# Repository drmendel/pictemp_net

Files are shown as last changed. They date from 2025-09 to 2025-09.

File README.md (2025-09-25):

<div align="center">
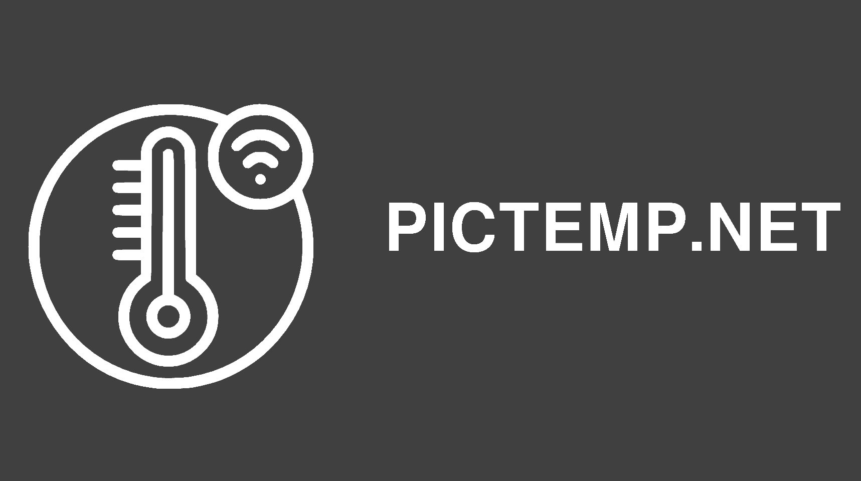
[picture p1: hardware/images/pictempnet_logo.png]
PICTEMP.NET Logo
  
</div>

## Overview

The **`PICTEMP.NET`** is a standalone IoT temperature sensor based on the *PIC18F97J60*, featuring TCP access over Ethernet using the *ENC28J60* ethernet controller. Includes custom firmware built on the Microchip TCP/IP stack and a compact KiCad-designed PC (similar to *PICDEM2.NET*) ideal for IoT, home automation, and industrial monitoring.

The project demonstrates a full-stack IoT solution:

- **Hardware**: A compact, efficient PCB designed in *KiCad*
- **Firmware**: Integrating sensor acquisition and network communication based on *Microchip Solutions v2011-06-02 TCP/IP Demo App*

The project was tested on the *PICDEM2.NET* development board, which ensured the firmware functionality before transitioning to the custom PCB.

## Hardware

### Core Components

- **Microcontroller:** PIC18F97J60  
- **Ethernet Controller:** ENC28J60 (external)  
- **Temperature Sensor:** TC1047x47  
- **Clock Sources:** 25 MHz, 32 kHz crystals  
- **Power Regulation:** LM2940S-5.0, TC1262-3.3  
- **LCD Display:** LCM-S01602DTR_M  
- **Connectivity:** RJ-12, RJ-45, barrel jack, pushbutton, testpoints

*The full list is available in [*pictempnet.csv*](hardware/pictempnet.csv).*

### Design priorities

- Compact footprint for embedded deployment  
- Efficient routing for signals and power  
- Smaller size to reduce cost and complexity    

### PCB Layout

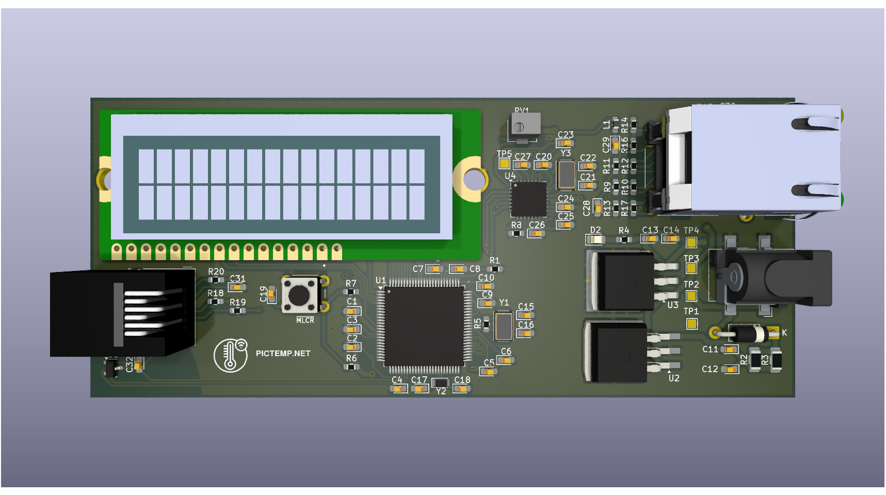
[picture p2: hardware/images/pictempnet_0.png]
PICTEMP.NET PCB Top Layer
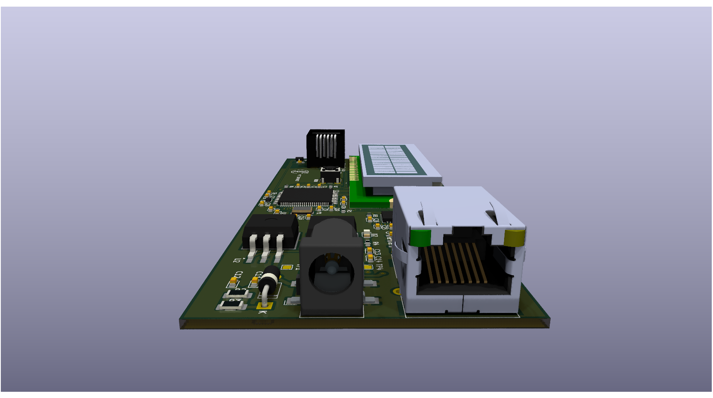
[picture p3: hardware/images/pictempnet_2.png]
PICTEMP.NET PCB Top Layer
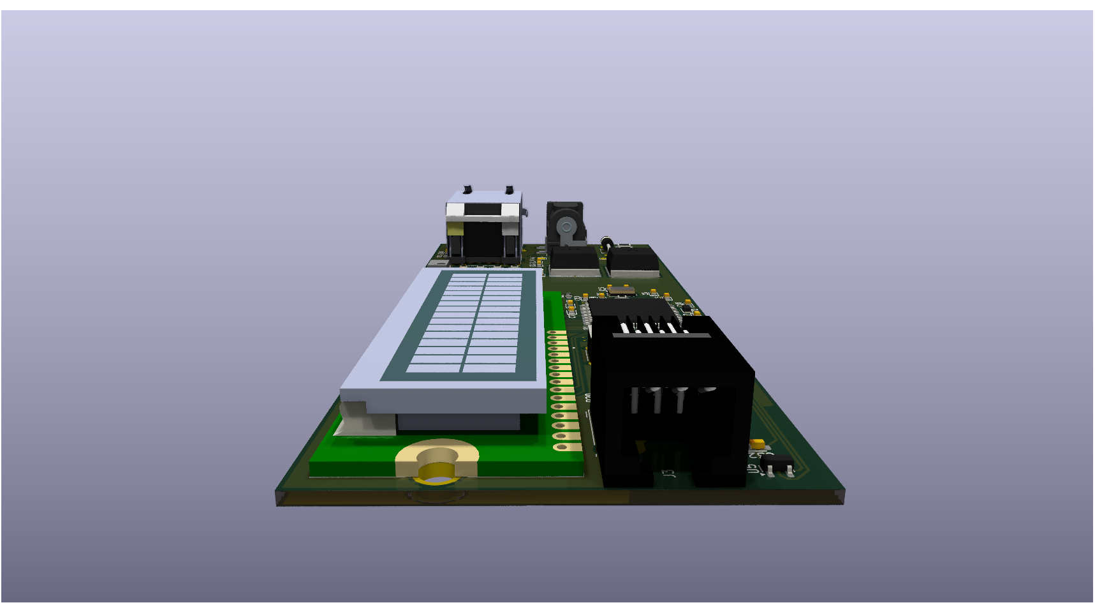
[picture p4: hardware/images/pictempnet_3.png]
PICTEMP.NET PCB Top Layer
|  |  |  |
|-|-|-|
| *Top view* | *Right view* | *Left view* |

*More images are available in the [images/](hardware/images) folder.*

## Firmware Architecture

The firmware is based on *Microchip Solutions v2011-06-02 TCP/IP Demo App*, modified to implement temperature sensing functionality. Key components include:  

- *`temperature_sensor.h` / `temperature_sensor.c`* – Interfaces directly with the temperature sensor IC, reading real-time measurements and providing functions to access the data.    
- *`GenericTCPIPServer.c`* – Derived from Microchip sources, enhanced for temperature sensor integration and real-time TCP access.

The firmware manages:  

- TCP connection handling and client requests  
- Temperature sensor sampling on TCP request
- Data buffering and formatting
- Efficient, low-latency response for real-time monitoring  

## Usage

### Project Configuration

The firmware is developed using *Microchip MPLAB X IDE*. It is strongly recommended to compile the project with this IDE due to complex configuration requirements.

In the project properties, set the following options:

- **Categories:** `C18-PICDN2_ENC28`  
- **Device:** `PIC18F97J60`  
- **Compiler Toolchain:** *[`C18 v3.47`](https://mplab-c18.software.informer.com/download/)*  

### Steps to Use

1. **Flash** the firmware to the custom *PCB* or the *PICDEM2.NET* development board.  
2. **Connect** the device to your network via Ethernet. The LCD will display the assigned IP address.  
3. **Access** temperature readings by sending the character `'t'` or `'T'` to *TCP port 2000*.

## Licensing

- **Hardware design**: Licensed under the [CERN-OHL-W-2.0](./hardware/LICENSE).  
- **Firmware**: Licensed under the terms of the [MICROCHIP SOFTWARE LICENSE AGREEMENT](./firmware/LICENSE).  

By **`DOWNLOADING`** or **`USING`** any part of this repository (including but not limited to source code, hardware design files, schematics, documentation, and images) through methods such as:
  - cloning the repository (`git clone ...`)  
  - downloading release archives (`.zip` / `.tar.gz`)  
  - forking the repository  
  - downloading individual files via the GitHub web interface  
  - retrieving the repository via GitHub API or GitHub CLI  
  - mirroring the repository

you **`AGREE`** to the applicable license terms, including the [MICROCHIP SOFTWARE LICENSE AGREEMENT](./firmware/LICENSE).

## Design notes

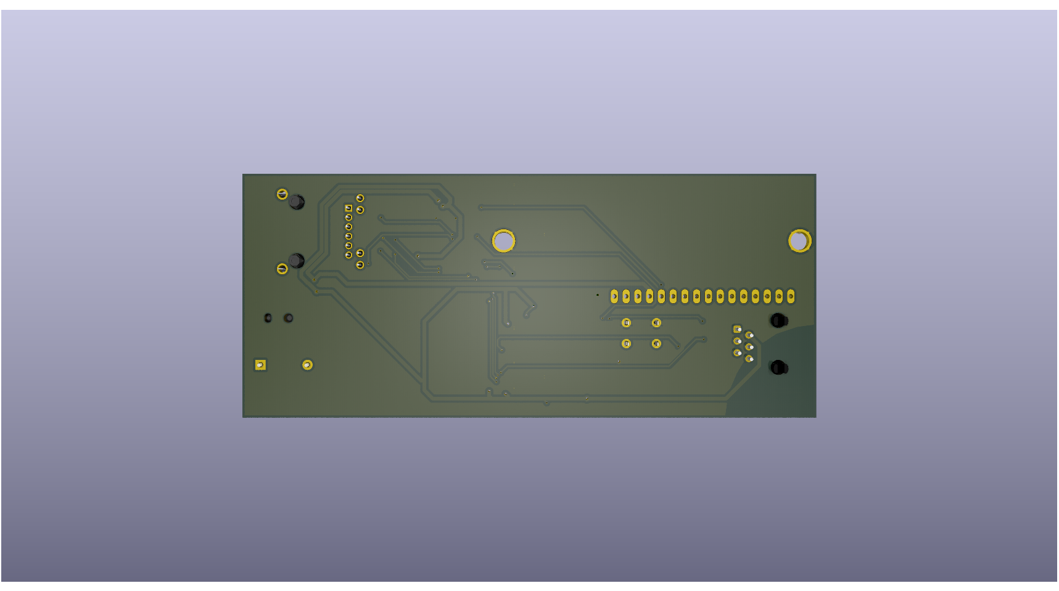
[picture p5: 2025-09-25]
hardware/images/pictempnet_1.png

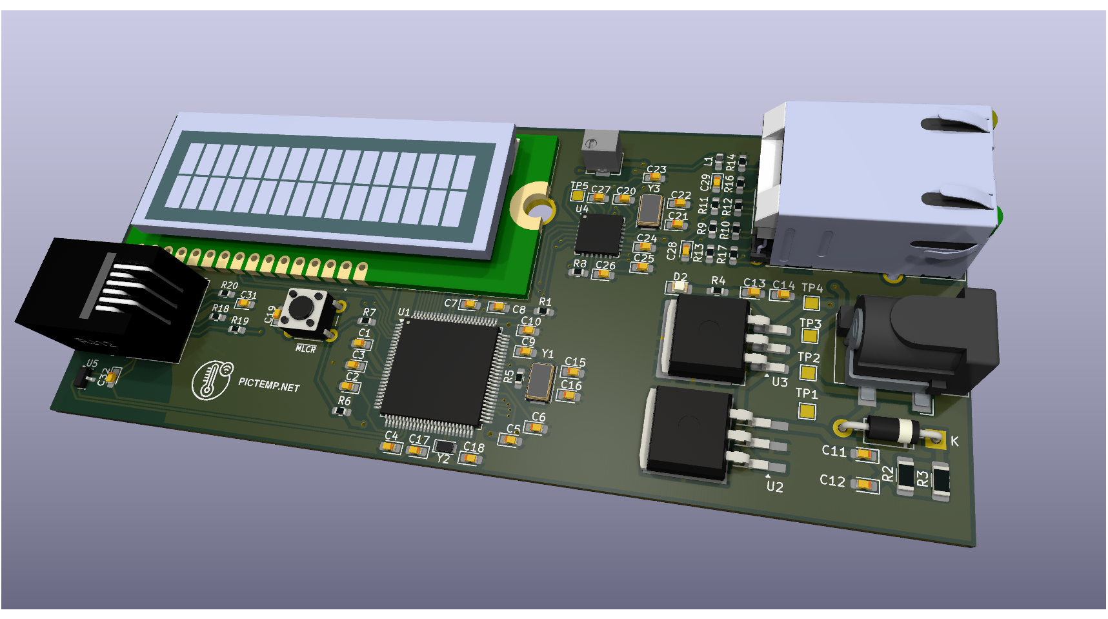
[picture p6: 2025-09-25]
hardware/images/pictempnet_4.png

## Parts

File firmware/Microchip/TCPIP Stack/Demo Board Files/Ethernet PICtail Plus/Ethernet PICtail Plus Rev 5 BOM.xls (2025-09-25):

02-01898 Rev 5 |  |  |  | PICtail Plus Ethernet
Count | ComponentName | RefDes | Value | Description | Vendor | Vendor # | Digikey # | RoHS
1 |  | U3 | ENC28J60 | Ethernet IC | Microchip |  |  | TRUE
7 | CAP0603 | C2, C3, C4, C6, C7, C13, C14 | .1uF | CAP SMT, 0.1uF 0603 CER 16V 10% X7R | NIC COMPONENTS CORP | NMC0603X7R104K16TRPF |  | TRUE
2 | CAP0603 | C5, C17 | 33pf | CAP CER 33PF 50V C0G 5% 0603 | TDK Corporation | C1608C0G1H330J | 445-1275-1-ND | TRUE
1 | CAP0805 | C12 | 10uF | CAP CER 10UF 6.3V Y5V 0805 | Murata | GRM21BF50J106ZE01L | 490-1746-1-ND | TRUE
1 | CRYSTAL_CS10 | Y1 | 25Mhz | CRYSTAL 25.0000 MHZ 18PF SMD | CITIZEN | CS10-25.000MABJTR | 300-8105-1-ND | TRUE
4 | RES0603 | R3, R4, R5, R6 | 49.9, 1% | RES 49.9 OHM 1/16W 1% 0603 SMD | Rohm | MCR03EZPFX49R9 | RHM49.9HCT-ND | TRUE
5 | RES0603 | R2, R7, R9, R11, R12 | 180 | RES 180 OHM 1/10W 5% 0603 SMD | Rohm | MCR03EZPJ181 | RHM180GCT-ND | TRUE
0 | RES0603 | R10 | No Load |  |  |  |  | N/A
1 | RES0603 | R8 | 2.32K, 1% | RES 2.32K OHM 1/10W 1% 0603 SMD | Rohm | MCR03EZPFX2321 | RHM2.32KHCT-ND | TRUE
1 | INDUCTOR-1210 | L1 | 60ohm | FERRITE 1.5A 60 OHM 1210 SMD | Steward | MI1210K600R-10 | 240-2416-1-ND | TRUE
1 |  | J1 |  | Mag Jack | Bel Stewart | 08B0-1X1T-36-F |  | TRUE
0 | Alternate | J1 |  | Pulse Jack | Pulse Engineering | JP011821UNL |  | TRUE

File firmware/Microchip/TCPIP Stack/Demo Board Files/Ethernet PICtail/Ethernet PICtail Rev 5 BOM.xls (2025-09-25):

02-01841 Rev 5 |  |  |  | Ethernet PICtail
Note: Use Vendor part number for reference, a few Digikey part numbers may be the lead version
Count | ComponentName | RefDes | Value | Description | Vendor | Vendor # | Digikey # | RoHS
1 | BRRECT-W02M | CR1 |  | RECTIFIER BRIDGE 1.5A 200V WOG | General Semiconductor | W02G-E4 | W02GGI-ND | TRUE
1 |  | U1 | 25C256 | EEPROM | Microchip | 25LC256-I/SN |  | TRUE
1 |  | U3 | ENC28J60 | Ethernet IC | Microchip | ENC28J60-I/ML |  | TRUE
1 | MC74VHCT125A-D | U2 |  | IC QUAD BUFF HS TRI-ST 14-SOIC | On Semiconductor | MC74VHCT125A-D | Newark 75C3053 | TRUE
1 | MC78XX_DPAC | Q2 |  | IC REGULATOR LDO 1A TO-263 | National Semiconductor | LM2940S-5.0/NOPB | LM2940S-5.0-ND | TRUE
0 | MC78XX_DPAC | Q1 | No Load | IC REGULATOR LDO TO-263 | National Semiconductor | LM3940IS-3.3 | LM3940IS-3.3-ND | N/A
1 | MC78XX_DPAC | Q1 |  | 500mA Fixed Output CMOS LDO | Microchip | TC1262-3.3VEB |  | TRUE
12 | CAP0603 | C1, C2, C3, C4, C6, C7, C8, C9, C11, C13, C14, C18 | .1uF | CAP SMT, 0.1uF 0603 CER 16V 10% X7R | NIC COMPONENTS CORP | NMC0603X7R104K16TRPF |  | TRUE
2 | CAP0603 | C5, C17 | 33pf | CAP CER 33PF 50V C0G 5% 0603 | TDK Corporation | C1608C0G1H330J | 445-1275-1-ND | TRUE
1 | CAP0805 | C12 | 10uF | CAP CER 10UF 6.3V Y5V 0805 | Murata | GRM21BF50J106ZE01L | 490-1746-1-ND | TRUE
2 | CAP B | C15, C16 | 33uF | CAP 33UF 10V ELECT VS SMD | Panasonic - ECG | EEE1AA330WR | PCE3175CT-ND | TRUE
1 | CAP_SMT_F | C10 | 220uF | CAP 220UF 25V ELECT VS SMD | Panasonic - ECG | EEE1EA221UP | PCE3187TR-ND | TRUE
1 | CRYSTAL_CS10 | Y1 | 25Mhz | CRYSTAL 25.0000 MHZ 18PF SMD | CITIZEN | CS10-25.000MABJTR | 300-8105-1-ND | TRUE
4 | RES0603 | R3, R4, R5, R6 | 49.9, 1% | RES 49.9 OHM 1/16W 1% 0603 SMD | Rohm | MCR03EZPFX49R9 | RHM49.9HCT-ND | TRUE
6 | RES0603 | R2, R7, R9, R10, R11, R12 | 180 | RES 180 OHM 1/10W 5% 0603 SMD | Rohm | MCR03EZPJ181 | RHM180GCT-ND | TRUE
1 | RES0603 | R8 | 2.7K, 1% | RES 2.70K OHM 1/10W 1% 0603 SMD | Rohm | MCR03EZPFX2701 | RHM2.70KHCT-ND | TRUE
1 | RES0603 | R1 | 100K | RES SMT, 100K-OHM 1/16W 5% 0603 | KOA | RK73B1JTTD104J |  | TRUE
1 | DJ005B | J11 |  | CONN, JACK, 2.5mm DC PC MOUNT | KYCON | KLD-0202-B |  | TRUE
1 | INDUCTOR-1210 | L1 | 60ohm | FERRITE 1.5A 60 OHM 1210 SMD | Steward | MI1210K600R-10 | 240-2416-1-ND | TRUE
1 | LED-0805 | D1 | GREEN | LED THIN 565NM GRN DIFF 0805 SMD | Lumex Opto | SML-LXT0805GW-TR | 67-1553-1-ND | TRUE
1 |  | J1 |  | Mag Jack | Bel Stewart | 08B0-1X1T-36-F |  | TRUE
0 | Alternate | J1 |  | Pulse Jack | Pulse Engineering | JP011821UNL |  | TRUE
1 |  | J2 |  | CONN HEADER .100 DUAL R/A 28POS | SAMTEC | TSW-114-08-G-D-RA |  | TRUE
1 |  | J3 |  | 2x14 header female | SAMTEC | SSW-114-01-T-D |  | TRUE
1 |  | None |  | 2x14 header female (ship loose in box) |  |  |  | TRUE
0 |  | J8, JP1, JP2, JP3 | No Load |  |  |  |  | N/A
0 |  | J4, J5, J6, J7 | No Load |  |  |  |  | N/A
1 |  | J9 |  | 1x3 header | SAMTEC | TSW-103-07-S-S |  | TRUE
1 | Load @ | J9 (pins 2&3) |  | 2 pin shorting jumper | AMP/TYCO | 382811-6 | A26227-ND | TRUE
0 |  | J10 | No Load | 2x6 header |  |  |  | N/A
1 |  | TP2 |  | TEST POINT, BLACK (0.063" HOLE) | COMPONENTS CORP | TP-106-01-00 |  | TRUE
2 |  | TP1, TP3 |  | TEST POINT, RED (0.063" HOLE) | COMPONENTS CORP | TP-106-01-02 |  | TRUE
Changes from Rev 3
C3 | Change from .01uF to .1uF
C12 | Change from electrolitic to ceramic
R12 | Add 200 ohm (new value)
R9 | Change from 100K to 200 ohm
R11 | Change from NL to 200 ohm
JP1, JP2, JP3 | Add No Load
C19 | Delete
Y1 | Change to new part
L1 | Change to RoHS part (-10 suffix)
C5, C17 | Change to 33pf
R9, R10, R11, R12 | Change to 180 Ohm

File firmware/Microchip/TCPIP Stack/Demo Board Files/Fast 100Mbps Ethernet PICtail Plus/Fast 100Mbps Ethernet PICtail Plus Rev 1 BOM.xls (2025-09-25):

02-02100 | Rev 1 |  | Microchip Fast 100Mbps Ethernet PICtailTM Plus
Count | RefDes | Value | Description | Vendor | Vendor Part Number | Mouser Part Number | Price 1 | Price 100 | Price 250 | Price 500 | Extension 100 | Extension 500 | RoHS | Comment
1 | U14 | NC7SZ57 | NOT NAND gate (SC70-6) | Fairchild Semiconductor | NC7SZ57P6X | 512-NC7SZ57P6X (http://www.mouser.com/Search/ProductDetail.aspx?qs=Q3c8oR7VdSob6m%252bML4LF0g%3d%3d) | $0.28 | $0.18 | $0.12 | $0.10 | $0.18 | $0.10 | TRUE
1 | U13 | NC7SZ04 | Inverter gate (SC70-5) | Fairchild Semiconductor | NC7SZ04P5X | 512-NC7SZ04P5X (http://www.mouser.com/Search/ProductDetail.aspx?qs=CR8BwU6haLeoOKbTbWr5WQ%3d%3d) | $0.19 | $0.12 | $0.08 | $0.07 | $0.12 | $0.07 | TRUE
1 | U3 | FST3125 | 4-bit Bus switch (TSSOP-14) | Fairchild Semiconductor | FST3125MTC | 512-FST3125MTC (http://www.mouser.com/Search/ProductDetail.aspx?qs=zGDcupr4zwNxWUl%252b5xBHsw%3d%3d) | $0.43 | $0.27 | $0.20 | $0.17 | $0.27 | $0.17 | TRUE
3 | U1, U2, U5 | FST3345 | 8-bit Bus switch (TSSOP-20) | Fairchild Semiconductor | FST3345MTC | 512-FST3345MTC (http://www.mouser.com/Search/ProductDetail.aspx?qs=MAkgEELEczQKCjIPKSg4pQ%3d%3d) | $0.52 | $0.22 | $0.19 | $0.17 | $0.66 | $0.52 | TRUE
1 | U8 | FST3257 | Quad 2:1 Multiplexer/Demultiplexer Bus Switch (TSSOP-16) | Fairchild Semiconductor | FST3257MTC | 512-FST3257MTC (http://www.mouser.com/Search/ProductDetail.aspx?qs=cbrHF9JAdyzaGwiPNvhfyw%3d%3d) | $0.52 | $0.30 | $0.22 | $0.19 | $0.30 | $0.19 | TRUE
1 | U4 | 74VHCT125 | Quad 3-state 5V TTL buffer (TSSOP-14) | On Semiconductor | MC74VHCT125ADTRG | 863-MC74VHCT125ADTRG (http://www.mouser.com/Search/ProductDetail.aspx?qs=%252b9%2fcbd0IE0Tn4bU7rbR7RQ%3d%3d) | $0.36 | $0.28 | $0.28 | $0.23 | $0.28 | $0.23 | TRUE
1 | D1 | MBR0540 | 500mA 50V Schottky Diode (SOD-123) | Fairchild Semiconductor | MBR0540 | 512-MBR0540 (http://www.mouser.com/Search/ProductDetail.aspx?qs=k%252b6EXM6KU1M%2f4zaj7pzWOw%3d%3d) | $0.11 | $0.08 | $0.07 | $0.05 | $0.08 | $0.05 | TRUE
1 | U6 | Si1307DL | 1.8V 0.91A P-Channel MOSFET (SC70-3) | Vishay Siliconix | SI1307DL-T1-E3 | 781-SI1307DL-E3 (http://www.mouser.com/Search/ProductDetail.aspx?qs=jcx%252b0HVgj2bRJdZ0ejbJbQ%3d%3d) | $0.28 | $0.23 | $0.23 | $0.22 | $0.23 | $0.22 | TRUE
1 | U7 | MCP1825 | 500mA 3.3V LDO with shutdown (SOT-223-5) | Microchip Technology | MCP1825T-3302E/DC | Microchip Direct: MCP1825T-3302E/DC (http://www.microchipdirect.com/productsearch.aspx?Keywords=MCP1825T-3302E%2fDC) | $0.00 | $0.00 | $0.00 | $0.00 | $0.00 | $0.00 | TRUE
1 | U9 | ENC624J600 | ENC624J600 10/100 Ethernet controller (TQFP-64 10x10x1) | Microchip Technology | ENC624J600-I/PT | 579-ENC624J600-I/PT (http://www.mouser.com/Search/ProductDetail.aspx?qs=sGAEpiMZZMvbYnN5EaJWBIREahSXEh7PrvOskHFN3mo%3d) | $0.00 | $0.00 | $0.00 | $0.00 | $0.00 | $0.00 | TRUE
1 | Y1 | 25MHz | Fundamental 25MHz +/-20PPM 18pF 500uW -20C to +70C crystal | ABRACON | ABMM-25.000MHZ-B2-T | 815-ABMM-25-B2-T (http://www.mouser.com/Search/ProductDetail.aspx?qs=aMAwYrhw3fjtGmDmGUYkhw%3d%3d) | $0.88 | $0.53 | $0.50 | $0.49 | $0.53 | $0.49 | TRUE
1 | J7 |  | Ethernet RJ-45 Jack with integrated magnetics and LEDs (-40C to +85C) | Bel Stewart | 08B0-1X1T-36-F | Arcadian Sales: 08B0-1X1T-36-F (http://arcadiansales.com/belbel-fusestewart-connector/rj45-connector-with-ethernet-andor-poe---poeplus/08B01X1T36F/) | $4.60 | $3.16 | $3.16 | $2.73 | $3.16 | $2.73 | TRUE
1 | R5 | 1M | 1M ohm 5% 0603 resistor | KOA Speer | RK73B1JTTD105J | 660-RK73B1JTTD105J (http://www.mouser.com/Search/ProductDetail.aspx?qs=MOfRNGxtlbKRrhpyH1P1mA%3d%3d) | $0.06 | $0.02 | $0.02 | $0.02 | $0.02 | $0.02 | TRUE
18 | R7, R13, R14, R23, R24, R25, R26, R27, R28, R29, R30, R34, R36, R37, R39, R43, R42, R45 | 100k | 100K ohm 5% 0603 resistor | KOA Speer | RK73B1JTTD104J | 660-RK73B1JTTD104J (http://www.mouser.com/Search/ProductDetail.aspx?qs=oWZKZnQ95OoPzlg%252bHmLYKg%3d%3d) | $0.06 | $0.02 | $0.004 | $0.004 | $0.29 | $0.07 | TRUE
1 | R22 | 12.4K | 12.4K ohm 1% 0603 resistor | Vishay/Dale | CRCW060312K4FKEA | 71-CRCW0603-12.4K-E3 (http://www.mouser.com/Search/ProductDetail.aspx?qs=8tsW7z%2fc78of4VB3wUPkkg%3d%3d) | $0.06 | $0.02 | $0.02 | $0.02 | $0.02 | $0.02 | TRUE
3 | R35, R40, R41 | 10k | 10K ohm 5% 0603 resistor | KOA Speer | RK73B1JTTD103J | 660-RK73B1JTTD103J (http://www.mouser.com/Search/ProductDetail.aspx?qs=hmtrJ2UjXcBKRTcwO9LloQ%3d%3d) | $0.06 | $0.02 | $0.02 | $0.02 | $0.06 | $0.05 | TRUE
1 | R4 | 1k | 1K ohm 5% 0603 resistor | KOA Speer | RK73B1JTTD102J | 660-RK73B1JTTD102J (http://www.mouser.com/Search/ProductDetail.aspx?qs=ySlnPdhAnF0vPhOsRGbH%252bQ%3d%3d) | $0.06 | $0.02 | $0.02 | $0.02 | $0.02 | $0.02 | TRUE
2 | R19, R20 | 180 | 180 ohm 5% 0603 resistor | KOA Speer | RK73B1JTTDD181J | 660-RK73B1JTTDD181J (http://www.mouser.com/Search/ProductDetail.aspx?qs=eQc%252bYniTHCeW0PXkL8Pyjg%3d%3d) | $0.05 | $0.01 | $0.01 | $0.003 | $0.01 | $0.01 | TRUE
4 | R1, R2, R3, R32 | 100 | 100 ohm 5% 0603 resistor | KOA Speer | RK73B1JTTD101J | 660-RK73B1JTTD101J (http://www.mouser.com/Search/ProductDetail.aspx?qs=WYsh1TcxAFWszMVYT3llKQ%3d%3d) | $0.06 | $0.02 | $0.02 | $0.02 | $0.08 | $0.06 | TRUE
4 | R8, R9, R17, R18 | 49.9 | 49.9 ohm 1% 0603 resistor | Vishay/Dale | CRCW060349R9FKEB | 71-CRCW060349R9FKEB (http://www.mouser.com/Search/ProductDetail.aspx?qs=C0xaqriB68iwcu6QmKL3vw%3d%3d) | $0.06 | $0.02 | $0.01 | $0.01 | $0.08 | $0.06 | TRUE
1 | R6 | 10 | 10 ohm 1% 1/12W 0603 resistor | Vishay/Dale | CRCW060310R0FKEB | 71-CRCW060310R0FKEB (http://www.mouser.com/Search/ProductDetail.aspx?qs=KP%252bPudsHLdwtRLMc%252bPMrxQ%3d%3d) | $0.06 | $0.02 | $0.02 | $0.02 | $0.02 | $0.02 | TRUE
1 | R15 | 0 | 0 ohm 5% 0603 resistor | Vishay/Dale | CRCW06030000Z0EA | 71-CRCW0603-0-E3 (http://www.mouser.com/Search/ProductDetail.aspx?qs=uFJqmf%2f3rbbVtxvMdbYUaQ%3d%3d) | $0.06 | $0.02 | $0.02 | $0.02 | $0.02 | $0.02 | TRUE
0 | R10, R11, R12, R16, R38 | No Load
1 | C11 | 10uF | 10uF +80%/-20% 4V 0805 ceramic capacitor | Murata | GRM219R60J106KE19D | 81-GRM219R60J106KE9D (http://www.mouser.com/Search/ProductDetail.aspx?qs=Ilq%252bLDnc%2fNgDxdJFi6Qw%252bA%3d%3d) | $0.09 | $0.08 | $0.08 | $0.07 | $0.08 | $0.07 | TRUE
1 | C6 | 4.7uF | 4.7uF +80%/-20% 6.3V 0603 ceramic capacitor | Murata | GRM188F50J475ZE20D | 81-GRM188F50J475ZE20 (http://www.mouser.com/Search/ProductDetail.aspx?qs=koHpCXkX%252bXWPno0u3vcZ7w%3d%3d) | $0.19 | $0.07 | $0.07 | $0.04 | $0.07 | $0.04 | TRUE
1 | C7 | 1uF | 1uF +80%/-20% 6.3V 0603 ceramic capacitor | Murata | GRM188R60J105KA01D | 81-GRM39R105K6.3 (http://www.mouser.com/Search/ProductDetail.aspx?qs=dddcrN876Gomyq%2fPjh7oaA%3d%3d) | $0.14 | $0.04 | $0.04 | $0.02 | $0.04 | $0.02 | TRUE
10 | C4, C8, C12, C17, C21, C23, C28, C31, C34, C37, | 0.1uF | 0.1uF +80%/-20% 16V 0603 ceramic capacitor | Kemet | C0603C104Z3VACTU | 80-C0603C104Z3V (http://www.mouser.com/Search/ProductDetail.aspx?qs=t9q%2f2xDdjt8I7iMfh2CPDg%3d%3d) | $0.05 | $0.01 | $0.01 | $0.01 | $0.06 | $0.05 | TRUE
10 | C9, C13, C15, C18, C22, C24, C29, C32, C35, C38 | 0.01uF | 0.01uF +80%/-20% 16V 0603 ceramic capacitor | Kemet | C0603C103J5RAC7411 | 80-C0603C103J5R7411 (http://www.mouser.com/Search/ProductDetail.aspx?qs=r%2fVmNO8Tjq5w03%252blhuR%2fbA%3d%3d) | $0.05 | $0.01 | $0.01 | $0.01 | $0.08 | $0.08 | TRUE
2 | C16, C20 | 6.8nF | 6.8nF +/-10% 16V 0603 ceramic capacitor | Kemet | C0603C682K5RACTU | 80-C0603C682K5R (http://www.mouser.com/Search/ProductDetail.aspx?qs=E5l%252bIPT91Puurjber%2feoHQ%3d%3d) | $0.05 | $0.02 | $0.01 | $0.01 | $0.04 | $0.01 | TRUE
2 | C26, C27 | 27pF | 27pF +/-5% 16V 0603 NP0/C0G ceramic capacitor | Kemet | C0603C270J5GACTU | 80-C0603C270J5G (http://www.mouser.com/Search/ProductDetail.aspx?qs=tmo4rc6ZD9Wc1Km2xObD4A%3d%3d) | $0.05 | $0.02 | $0.01 | $0.01 | $0.04 | $0.02 | TRUE
0 | C10, C19, C30, C33, C36, C39, C44 | No Load
3 | JP9, JP10, JP11 | 1x3 header | 1x3 pin thru-hole male header 0.1 inch pitch | Molex | 22-28-4032 | 538-22-28-4032 (http://www.mouser.com/Search/ProductDetail.aspx?qs=d9fIA1aNikShPBuXG7gmfA%3d%3d) | $0.11 | $0.09 | $0.08 | $0.06 | $0.27 | $0.18 | TRUE
4 | JP2, JP3, JP7, JP8 | 1x2 header | 1x2 pin thru-hole male header 0.1 inch pitch | Molex | 22-28-5020 | 538-22-28-5020 (http://www.mouser.com/Search/ProductDetail.aspx?qs=l%252bWx29wYPrzoqPHV3Welgw%3d%3d) | $0.08 | $0.07 | $0.06 | $0.05 | $0.26 | $0.20 | TRUE
1 | J4 | 2x14 header | 2x14 pin thru-hole male right angle header 0.1 inch pitch | Samtec | TSW-114-08-T-D-RA | Digikey: SAM1049-14-ND (http://search.digikey.com/scripts/DkSearch/dksus.dll?Detail&name=SAM1049-14-ND) | $2.45 | $1.81 | $1.81 | $1.43 | $1.81 | $1.43 | TRUE
1 | J3 | 2x3 header | 2x3 pin thru-hole male right angle header 0.1 inch pitch | Samtec | TSW-103-08-T-D-RA | Digikey: SAM1049-03-ND (http://search.digikey.com/scripts/DkSearch/dksus.dll?Detail&name=SAM1049-03-ND) | $1.68 | $1.24 | $1.24 | $0.98 | $1.24 | $0.98 | TRUE
0 | J6, J8, J9, J10 | No Load
6 | JP2, JP7, JP8, JP9, JP10, JP11 | Load@ JP2, (JP7, JP8 hang on one pin), (JP10 top two pins), (JP9, JP11 bottom two pins) | 1x2 pin jumper shunt 0.1 inch pitch | Sullins Connector Solutions | SPC02SYAN | Digikey: S9001-ND (http://search.digikey.com/scripts/DkSearch/dksus.dll?Detail&name=S9001-ND) | $0.09 | $0.07 | $0.05 | $0.05 | $0.44 | $0.29 | TRUE
0 | J5 | No Load
2 | TP3, TP4 |  | Test point, black (0.052" hole) | Kobiconn | 151-103-RC | 151-103-RC (http://www.mouser.com/Search/ProductDetail.aspx?qs=RH7ho1lbOmmmFptH%252bQFkig%3d%3d) | $0.30 | $0.20 | $0.15 | $0.13 | $0.40 | $0.26 | TRUE
1 | TP2 |  | Test point, red (0.052" hole) | Kobiconn | 151-107-RC | 151-107-RC (http://www.mouser.com/Search/ProductDetail.aspx?qs=iv5aS%252bKJODNJ8P%252bmN89Zyw%3d%3d) | $0.30 | $0.20 | $0.20 | $0.15 | $0.20 | $0.15 | TRUE
1 | - | 5' Cable | 5' Cat5e (or better) Ethernet patch cable | Cable and Connector Technologies | 5' Category 5e Patch Cable - Black | CCT: 5' Category 5e Patch Cable - Black (http://www.callcct.com/Shop/5-Category-5e-Patch-Cable) | $1.42 | $1.39 | $1.35 | $1.35 | $1.39 | $1.35
1 | - |  | PCB | Advanced Circuits |  |  | $5.00 | $5.00 | $5.00 | $5.00 | $5.00 | $5.00
 |  |  |  |  |  |  | Total |  |  |  | $17.83 | $15.25

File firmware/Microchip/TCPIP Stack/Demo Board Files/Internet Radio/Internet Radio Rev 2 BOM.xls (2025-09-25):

02-02027 | Rev 2 |  |  | Internet Radio
Count | ComponentName | RefDes | Value | Description | Vendor | Vendor # | Digikey # | RoHS
1 | DIODE | D4 |  | SMD Transient Voltage Suppression Arrays | AVX | MG054S05X150DP |  | TRUE
1 | DIODE_SOD-323 | D5 |  | DIODE SCHOTTKY 0.5A 20V SOD-123 | Fairchild Semiconductor | MBR0520L | MBR0520LCT-ND | TRUE
1 | MGSF1N02LT1_SOT23 | Q1 |  | MOSFET N-CHAN 750MA 20V SOT23 | ON Semiconductor | MGSF1N02LT1G | MGSF1N02LT1GOSCT-ND | TRUE
1 | PIC18F67J60 | U1 |  |  | Microchip | PIC18F67J60-I/PT |  | TRUE
1 | TC55-SOT89 | U5 |  | Voltage Regulator | Microchip | MCP1703T-3302E/MB |  | TRUE
2 | 23K256_SOIC150 | U4, U6 |  | 32K x 8 serial SRAM | Microchip | 23K256-I/SN |  | TRUE
1 | VS1011_LQFP48 | U2 |  | MP3 Decoder IC | VLSI | VS1011E-L |  | TRUE
1 | OLED_HS1101A | LCD1 |  |  |  |  |  | TRUE
1 | LED-0805 | D3 |  | LED THIN 565NM GRN DIFF 0805 SMD | Lumex Opto/Components | SML-LXT0805GW-TR | 67-1553-1-ND | TRUE
2 | CAP0603 | C27, C28 | 22pf | CAP CER 22PF 50V C0G 5% 0603 | TDK Corporation | C1608C0G1H220J | 445-1273-1-ND | TRUE
2 | CAP0603 | C7, C8 | 33pf | CAP CER 33PF 50V C0G 5% 0603 | TDK Corporation | C1608C0G1H330J | 445-1275-1-ND | TRUE
1 | CAP0603 | C30 | 1nF | CAP 1000PF 100V CERAMIC X7R 0603 | Panasonic - ECG | ECJ-1VB2A102K | PCC1952TR-ND | TRUE
2 | CAP0603 | C35, C36 | 10nF | CAP 10000PF 25V CERM X7R 0603 | Panasonic - ECG | ECJ-1VB1E103K | PCC1763TR-ND | TRUE
2 | CAP0603 | C26, C37 | 47nF | CAP 47000PF 50V CERM Y5V 0603 | Panasonic - ECG | ECJ-1VF1H473Z | PCC1805TR-ND | TRUE
17 | CAP0603 | C1, C2, C3, C4, C5, C6, C10, C11, C14, C15, C18, C23, C25, C29, C32, C38,C39 | .1uF | CAP .1UF 16V CERAMIC Y5V 0603 | Panasonic - ECG | ECJ-1VF1C104Z | PCC1788TR-ND | TRUE
3 | CAP0603 | C9, C16, C19 | 1uF | CAP SMT, 1.0uF 0603 CER 16V 10% X5R | PANASONIC | ECJ-1VB1C105K | PCC2224CT-ND | TRUE
1 | CAP0603 | C13 | 4.7uF | CAP CERAMIC 4.7UF 6.3V X5R 0603 | Panasonic - ECG | ECJ-1VB0J475M | PCC2318CT-ND | TRUE
1 | CAP0805 | C31 | 2.2uF | CAP 2.2UF 25V CERAMIC F 0805 | Panasonic - ECG | ECJ-2FF1E225Z | PCC2231CT-ND | TRUE
1 | CAP0805 | C20 | 10uF | CAP CER 10UF 6.3V Y5V 0805 | Murata | GRM21BF50J106ZE01L | 490-1746-1-ND | TRUE
1 | CAP3528 | C34 | 6.8uF | CAP TANTALUM 6.8UF 16V 20% SMD | Kemet | B45196H3685M209 | 495-2235-1-ND | TRUE
1 | CAP_POL_3528 | C17 | 10uF | CAPACITOR TANT 10UF 16V 10% SMD | Kemet | T491B106K016AT | 399-3706-1-ND | TRUE
1 | CAP_SMT_F | C33 | 220uF | CAP 220UF 25V ELECT VS SMD | Panasonic - ECG | ECE-V1EA221UP | PCE3187CT-ND | TRUE
1 | CC_1008LS | L3 | 10uH | 1008PS Series Power Chip Inductors | COILCRAFT | 1008PS-103KLB |  | TRUE
1 | DO1606 | L2 | 10uH | 1606 Series Power Chip Inductors | COILCRAFT | DO1606T-103MBL |  | TRUE
1 | INDUCTOR-1210 | L1 | 60ohm | FERRITE 1.5A 60 OHM 1210 SMD | Steward | MI1210K600R-10 | 240-2416-1-ND | TRUE
1 | CRYSTAL_CS10 | Y1 | 25Mhz | CRYSTAL 25.0000 MHZ 18PF SMD | CITIZEN | CS10-25.000MABJTR | 300-8105-1-ND | TRUE
1 | CRYSTAL_CS10 | Y2 | 24.576Mhz | CRYSTAL 24.5760 MHZ 18PF SMD | CITIZEN | CS10-24.576MABJ-UT | 300-8104-1-ND | TRUE
1 |  | J1 |  | Mag Jack | Bel Stewart | 08B0-1X1T-36-F |  | TRUE
1 | DJ005B | J3 |  | CONN JACK POWER 2.1MM PCB | CUI Inc | PJ-102A | CP-102A-ND | TRUE
1 | PHONE_SJ3505 | J2 |  | CONN 3.5MM RTANG STEREO JACK PCB | CUI Inc | SJ-3505 | CP-3505-ND | TRUE
1 | RJ11_6PIN | J4 |  | CONN, MOD JACK 6-6 SIDE ENTRY LOW PROFILE | AMP/TYCO | 555165-1 | A9031-ND | TRUE
3 | RES0603 | R29, R30, R31 | 10 Ohm | RES 10 OHM 1/10W 5% 0603 SMD | Panasonic - ECG | ERJ-3GEYJ100V | P10GTR-ND | TRUE
2 | RES0603 | R20, R21 | 20 Ohm | RES 20 OHM 1/10W 5% 0603 SMD | Panasonic - ECG | ERJ-3GEYJ200V | P20GTR-ND | TRUE
4 | RES0603 | R4, R5, R7,R8 | 49.9, 1% | RES 49.9 OHM 1/16W 1% 0603 SMD | Rohm | MCR03EZPFX49R9 | RHM49.9HCT-ND | TRUE
3 | RES0603 | R6, R9, R12 | 180 | RES 180 OHM 1/10W 5% 0603 SMD | Rohm | MCR03EZPJ181 | RHM180GCT-ND | TRUE
1 | RES0603 | R2 | 2.26K, 1% | RES 2.26K OHM 1/10W 1% 0603 SMD | Panasonic - ECG | ERJ-3EKF2261V | P2.26KHCT-ND | TRUE
6 | RES0603 | R10, R11, R14, R17, R18, R23 | 10K | RES SMT, 10K-OHM 1/10W 5% 0603 | Panasonic - ECG | ERJ-3GEYJ103V | P10KGTR-ND | TRUE
4 | RES0603 | R22, R32, R33, R34 | 100K | RES 100K OHM 1/10W 5% 0603 SMD | Panasonic - ECG | ERJ-3GEYJ104V | P100KGTR-ND | TRUE
1 | RES0603 | R16 | 110K 1% | RES 110K OHM 1/10W 1% 0603 SMD | Panasonic - ECG | ERJ-3EKF1103V | P110KHTR-ND | TRUE
1 | RES0603 | R13 | 820K | RES 820K OHM 1/10W 5% 0603 SMD | Panasonic - ECG | ERJ-3GEYJ824V | P820KGTR-ND | TRUE
1 | RES0603 | R15 | 931K 1% | RES 931K OHM 1/10W 1% 0603 SMD | Panasonic - ECG | ERJ-3EKF9313V | P931KHTR-ND | TRUE
1 | RES0603 | R19 | 1M | RES SMT, 1.0M-OHM 1/10W 5% 0603 | YAGEO/PHYCOMP | RC0603JR-071ML |  | TRUE
1 | RES0805 | R24 | 0.12 ohm | RES .12 OHM 1/2W 1% 1206 SMD | Susumu Co Ltd | RL1632R-R120-F | RL16R.12FCT-ND | TRUE
2 | RES1206 | R25, R26 | 2 Ohm | RES 2.00 OHM 1/4W 1% 1206 SMD | Rohm | MCR18EZHFL2R00 | RHM2.00FCT-ND | TRUE
3 | SW-PUSH_SMT | S1, S2, S3 |  | SWITCH LT TOUCH 6X3.5 100GF SMD | Panasonic - ECG | EVQ-PJS04K | P8048SCT-ND | TRUE
4 |  |  |  | BUMPON TALL TAPER SQ .50X.23 BK | 3M/ESM | SJ-5518 (BLACK) | SJ5518-0-ND | TRUE
0 | SIP_4 |  | No Load
1 | PCB |  |  |  | Advanced Circuits | 05-60142_REV_C |  | TRUE

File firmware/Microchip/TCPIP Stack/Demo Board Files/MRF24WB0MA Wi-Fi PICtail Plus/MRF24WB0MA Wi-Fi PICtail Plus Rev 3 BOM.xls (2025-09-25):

02-02122 | Rev 3 |  |  | MRF24WB0MA Wi-Fi PICtail Plus Daughter Board
Count | ComponentName | RefDes | Value | Discription | Vendor | Vendor # | Digikey # | Mouser # | Price | Extension | RoHS | Comments
1 | G2100_Module | U1 |  | 2.4GHz 802.11b Ultra Low Power Transceiver | Microchip | MRF24WB0MA |  |  | $0.000 | $0.000 | TRUE
1 | MCP1700_SOT89 | U2 |  | CMOS low dropout positive voltage regulator | Microchip | MCP1700T-3302E/MB |  |  | $0.000 | $0.000 | TRUE
3 | CAP0402 | C1, C2, C3 | 1uF | CAP 1UF 6.3V CERAMIC X5R 10% 0603 | Murata | GRM188R60J105KA01D |  | 81-GRM39R105K6.3 | $0.036 | $0.108 | TRUE
1 | CAP1206 | C4 | 100uF | Tantalum Cap 100uF 6.3volts 10% "C" case | Vishay/Sprague | 293D107X96R3C2TE3 | 718-1058-2-ND |  | $0.226 | $0.226 | TRUE
5 | RES0603 | R1, R2. R3. R4. R9 | 10K | RES 4.7K OHM 1/10W 5% 0603 SMD | Panasonic - ECG | ERJ-3GEYJ472V | P4.7KGTR-ND |  | $0.004 | $0.022 | TRUE
1 | RES0603 | R6 | 10K | RES 10K OHM 1/10W 5% 0603 SMD | Panasonic - ECG | ERJ-3GEYJ103V | P10KGTR-ND |  | $0.004 | $0.004 | TRUE
1 | RES0603 | R7 | 1M | RES 1.0M OHM 1/10W 5% 0603 SMD | Panasonic - ECG | ERJ-3GEYJ105V | P1.0MGTR-ND |  | $0.004 | $0.004 | TRUE
0 | RES0603 | R5 | No Load
0 | HDR2X4 | J4 | No Load
0 | TP-125R63 | TP1, TP2 | No Load
1 | HDR2X14 | J1 | (28 pins) | CONN HEADER .100 DUAL R/A 72POS | Sullins Electronics Corp. | PZC36DBDN | S2141-36-ND |  | $2.810 | $2.81 | TRUE | Cut to 2x14 pins
1 | PCB |  |  |  | Advanced Circuits | 05-02122_REV3 |  |  | $5.000 | $5.000 | TRUE
 |  |  |  |  |  |  |  |  | Total | $8.175
Changes from Rev 1 of ZeroG ZG2100M Wi-Fi PICtail Plus
U1 new part number (was ZG2100M, now MRF24WB0MA)
C1, C2, C3 new part number and package (was 0402, now 0603)
C4 new part number and package (was ceramic, now 6032 "C" case tantalum)
R7 new part number (was 10K, now 1M)
J3 (1x3 SIP header) was removed from PCB and BOM

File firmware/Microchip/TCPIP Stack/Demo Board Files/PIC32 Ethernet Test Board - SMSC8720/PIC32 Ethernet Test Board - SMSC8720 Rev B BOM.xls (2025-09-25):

Board Number: 02-90019
Board Desription: PIC32MX ENET TEST BD |  |  |  | Date: 07-20-2010
Rev:B
DNP | Qty | Description | Reference | Footprint | Mfgr. | Mfgr. PN | Disti | Disti PN | RoHS?
 | 12 | C28, C33, C1, C19, C20, C21, C22, C23, C24, C35, C36, C37, C27, C31 | CAP CER .10UF 25V X7R 0603 | CAP0603 | TDK | C1608X7R1E104M | Digi-Key | 445-5111-1-ND | Y
 | 1 | C38 | CAP CER 1.0UF 10V X7R 0603 | CAP0603 | TDK | C1608X7R1A105K | Digi-Key | 445-5138-1-ND (http://search.digikey.com/scripts/DkSearch/dksus.dll?Detail&name=445-5138-1-ND) | Y
 | 2 | C15,C16 | CAP CER 12PF 50V 5% C0G 0603 | CAP0603 | Murata | GRM1885C1H120JA01D | Digi-Key | 490-1405-1-ND (http://search.digikey.com/scripts/DkSearch/dksus.dll?Detail&name=490-1405-1-ND) | Y
 | 2 | C5,C6 | CAP CER 20PF 50V C0G 0603 | CAP0603 | TDK | C1608C0G1H200J | Digi-Key | 445-5052-1-ND (http://search.digikey.com/scripts/DkSearch/dksus.dll?Detail&name=445-5052-1-ND) | Y
 | 2 | C29, C39 | CAP CER 18PF 50V C0G 5% 0603 | CAP0603 | TDK | C1608C0G1H180J | Digi-Key | 445-1272-2-ND (http://search.digikey.com/scripts/DkSearch/dksus.dll?Detail&name=445-1272-2-ND) | Y
 | 2 | C7, C8 | CAP CER 4.7UF 10V X7R 20% 0805 | CAP0805 | TDK | C2012X7R1A475M | Digi-Key | 445-1605-1-ND (http://search.digikey.com/scripts/DkSearch/dksus.dll?Detail&name=445-1605-1-ND) | Y
 | 2 | C2,C32 | CAP CER 10UF 10V Y5V 0805 | CAP0805 | TDK | C2012Y5V1A106Z | Digi-Key | 445-1371-1-ND (http://search.digikey.com/scripts/DkSearch/dksus.dll?Detail&name=445-1371-1-ND) | Y
 | 1 | C34 | CAP CER 10UF 25V 10% X7R 1210 | CAP1210 | Murata | GRM32DR71E106KA12L | Digi-Key | 490-1867-1-ND (http://search.digikey.com/scripts/DkSearch/dksus.dll?Detail&name=490-1867-1-ND) | Y
 | 4 | C40, C41, C42, C43 | CAP CER 10PF 50V C0G 0603 | CAP0603 | TDK | C1608C0G1H100D | Digi-Key | 445-1269-1-ND (http://search.digikey.com/scripts/DkSearch/dksus.dll?Detail&name=445-1269-1-ND) | Y
 | 1 | J6 | CONN MAGJACK 1PORT SHLD 10/100BT | SI-60062-F | Stewart Connector | SI-60062-F | Digi-Key | 380-1106-ND | Y
 | 1 | Y3 | 32.000 KHZ 12.5PF CYL | CRYSTAL_32KHZ | ECS Inc. | ECS-.320-12.5-13X | Digi-Key | XC1392-ND (http://search.digikey.com/scripts/DkSearch/dksus.dll?Detail&name=XC1392-ND) | Y
 | 1 | Y4 | 25.000MHZ 18PF FUND SMD | CRYSTAL_ABM3B | Abracon | ABM3B-25.000MHZ-B2-T | Digi-Key | 535-9128-1-ND (http://search.digikey.com/scripts/DkSearch/dksus.dll?Detail&name=535-9128-1-ND) | Y
 | 1 | Y2 | CRYSTAL 8.0 MHZ 20PF SMD | CRYSTAL_FQ_5X7 | Fox | FQ7050B-8.000 | Digi-Key | 631-1029-1-ND | Y
 | 1 | D8 | DIODE SCHOTTKY 30V 1A PMDU | DIODE_SOD-123 | Rohm | RB160M-30TR | Digi-Key | RB160M-30CT-ND (http://search.digikey.com/scripts/DkSearch/dksus.dll?Detail&name=RB160M-30CT-ND) | Y
 | 1 | J17 | DC Power Connectors 2mm PCB JACK POWER JACK | DJ005B | KYCON | KLDX-0202-A | Mouser | 806-KLDX-0202-A | Y
 | 1 | FB1 | FERRITE CHIP 600 OHM 500MA 0805 | FERRITE_0805 | TDK | MMZ2012Y601B | Digi-Key | 445-1558-1-ND (http://search.digikey.com/scripts/DkSearch/dksus.dll?Detail&name=445-1558-1-ND) | Y
 | 1 | P5 | CONN HEADER 25POS SNGL 1.27MM T/H | 100_PIM | Samtec | TMS-125-01-G-S | N/A | N/A | Y
 | 1 | J8 | CONN HEADER 10POS .100" DL TIN | HDRC-2X5 | Samtec | TSW-105-07-T-D | DKC | SAM1034-05-ND | Y
 | 1 | J13 | CONN HEADER 14POS .100" DL TIN | HDRC-2X7 | Samtec | TSW-107-07-T-D | DKC | SAM1034-07-ND | Y
 | 1 | U7 | TXRX ETHERNET 10/100 RMII 24QFN | LAN8720_QFN24 | SMSC | LAN8720A-CP | Digi-Key | 638-1080-ND (http://search.digikey.com/scripts/DkSearch/dksus.dll?Detail&name=638-1080-ND) | Y
 | 1 | D3 | LED GREEN CLEAR 0805 SMD | LED_0805 | LITE-ON INC | LTST-C170GKT | Digi-Key | 160-1179-1-ND | Y
 | 1 | U3 | IC REG LDO 800MA 5.0V SOT-223 | LM1117-SOT223 | National | LM1117MP-5.0/NOPB | Digi-Key | LM1117MP-5.0CT-ND (http://search.digikey.com/scripts/DkSearch/dksus.dll?Detail&name=LM1117MP-5.0CT-ND) | Y
 | 1 | U2 | PIC32MX 100L_TQF | USB_TQFP100 | MicroChip |  |  |  | Y
 | 6 | R8, R9, R11, R12, R13, R20 | RES 0.0 OHM 1/10W 5% 0603 SMD | RES0603 | ROHM | MCR03EZPJ000 | Digi-Key | RHM0.0GCT-ND | Y
DNP | 6 | R14, R15, R16, R17, R18, R21 | RES 0.0 OHM 1/10W 5% 0603 SMD | RES0603 | ROHM | MCR03EZPJ000 | Digi-Key | RHM0.0GCT-ND | Y
 | 1 | R10 | RES 4.70K OHM 1/10W 1% 0603 SMD | RES0603 | ROHM | MCR03EZPFX4701 | Digi-Key | RHM4.70KHCT-ND | Y
 | 5 | R3, R4, R5, R6, R7 | RES 22 OHM 1/10W 5% 0603 SMD | RES0603 | Stackpole | RMCF 1/16 22 5% R | Digi-Key | RMCF1/1622JRCT-ND (http://search.digikey.com/scripts/DkSearch/dksus.dll?Detail&name=RMCF1/1622JRCT-ND) | Y
 | 1 | R19 | RES 330 OHM 1/10W 1% 0603 SMD | RES0603 | ROHM | MCR03EZPFX3300 | Digi-Key | RHM330HCT-ND | Y
 | 1 | R57 | RES 1M OHM 1/10W 5% 0603 SMD | RES0603 | Stackpole | RMCF 1/16 1M 5% R | Digi-Key | RMCF1/161MJRCT-ND (http://search.digikey.com/scripts/DkSearch/dksus.dll?Detail&name=RMCF1/161MJRCT-ND) | Y
 | 1 | R55 | RES 1.5K OHM 1/10W 5% 0603 SMD | RES0603 | Stackpole | RMCF 1/16 1.5K 5% R | Digi-Key | RMCF1/161.5KJRCT-ND (http://search.digikey.com/scripts/DkSearch/dksus.dll?Detail&name=RMCF1/161.5KJRCT-ND) | Y
 | 1 | R56 | RES 10.0K OHM 1/10W 1% 0603 SMD | RES0603 | Yageo | RC0603FR-0710KL | Digi-Key | 311-10.0KHRCT-ND | Y
 | 1 | R50 | RES 12.1K OHM 1/10W 1% 0603 SMD | RES0603 | Stackpole | RMCF 1/16 12.1K 1% R | Digi-Key | RMCF1/1612.1KFRCT-ND (http://search.digikey.com/scripts/DkSearch/dksus.dll?Detail&name=RMCF1/1612.1KFRCT-ND) | Y
 | 6 | R59, R60, R61, R62, R63, R64 | RES 33 OHM 1/10W 5% 0603 SMD | RES0603 | Stackpole | RMCF 1/16 33 5% R | Digi-Key | RMCF1/1633JRCT-ND (http://search.digikey.com/scripts/DkSearch/dksus.dll?Detail&name=RMCF1/1633JRCT-ND) | Y
 | 4 | R37, R39, R40, R41 | RES 49.9 OHM 1/10W 1% 0603 SMD | RES0603 | Stackpole | RMCF 1/16 49.9 1% R | Digi-Key | RMCF1/1649.9FRCT-ND (http://search.digikey.com/scripts/DkSearch/dksus.dll?Detail&name=RMCF1/1649.9FRCT-ND) | Y
 | 2 | R28, R44 | RES 249 OHM 1/10W 1% 0603 SMD | RES0603 | Stackpole | RMCF 1/16 249 1% R | Digi-Key | RMCF1/16249FRCT-ND (http://search.digikey.com/scripts/DkSearch/dksus.dll?Detail&name=RMCF1/16249FRCT-ND) | Y
DNP | 1 | R58 | RES 10.0K OHM 1/10W 1% 0603 SMD | RES0603 | Panasonic-ECG | ERJ-3EKF1002V | DKC | P10.0KHCT-ND | Y
 | 1 | JP1 | MOD JACK 6-6 RT/A PCB 50AU | RJ11_6PIN | Tyco | 5520470-3 | Digi-Key | A31417-ND | Y
 | 1 | S1 | SWITCH TACT 6MM 160GF H=4.3MM | SW_PUSH_SMT | Omron | B3S-1000P | DKC | SW836CT-ND
 | 1 | U5 | IC CMOS LDO 3.3V 500MA SOT223-3 | 23 | Microchip | TC1262-3.3VDBTR | Digi-Key | TC1262-3.3VDBCT-ND (http://search.digikey.com/scripts/DkSearch/dksus.dll?Detail&name=TC1262-3.3VDBCT-ND) | Y
 | 2 | TP9, TP10 | TEST POINT PC MULTI PURPOSE RED | TP-ID65 | Keystone | 5010 | Digi-Key | 5010K-ND | Y
 | 1 | GND | TEST POINT PC MULTI PURPOSE BLK | TP-ID65 | Keystone | 5011 | Digi-Key | 5011K-ND | Y
 | 4 | TP11, TP12, TP13, TP14 | TEST POINT PC MULTI PURPOSE WHT | TP-ID65 | Keystone | 5012 | Digi-Key | 5012K-ND | Y

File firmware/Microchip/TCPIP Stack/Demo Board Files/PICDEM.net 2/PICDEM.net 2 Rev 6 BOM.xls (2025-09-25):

02-01935 Rev 6 |  |  |  | PICDEM.net 2
Count | ComponentName | RefDes | Value | Description | Vendor | Vendor # | Digikey # | RoHS
1 |  | D10 | IN4001 | RECTIFIER GPP 400V 1A SMB | DIODES INC | S1GB-13-F | S1GB-FDICT-ND | TRUE
1 |  | U4 | 25C256 | EEPROM | Microchip | 25LC256-I/SN |  | TRUE
1 |  | U2 | ENC28J60 | Ethernet IC | Microchip | ENC28J60/MLC01 |  | TRUE
1 | TC1047_SOT23 | U1 |  | IC SMT, TC1047A, 3L SOT-23 | Microchip | TC1047AVNBTRG |  | TRUE
2 | NC7SB3157_SC70_6 | U6, U7 |  | Multiplexer UHS SPDT Analog Switch | Fairchild Semiconductor | NC7SB3157P6X | NC7SB3157P6XCT-ND | TRUE
1 | MAX232A-SO16 | U5 | MAX232 | IC DRVR/RCVR MULTCH RS232 16SSOP | Texas Instruments | MAX3232CDBR | 296-13093-1-ND | TRUE
1 | MC78XX_DPAK | Q1 |  | IC SMT, REG, +5V 1A SOT-263 | NATIONAL SEMI | LM2940CS-5.0 NOPB | LM2940S-5.0-ND | TRUE
1 | MC78XX_DPAK | Q2 |  | IC SMT, TC1262-3.3, DDPAK | Microchip | TC1262-3.3VEB |  | TRUE
1 | PIC18F97J60-TQF | U3 |  |  | Microchip | PIC18F97J60-I/PT |  | TRUE
32 | CAP0603 | C1, C10, C11, C12, C13, C15, C16, C17, C18, C20, C21, C22, C23, C24, C26, C28, C29, C31, C32, C33, C36, C37, C38, C39, C40, C41, C42, C43, C44, C47, C50, C52 | 0.1uF | CAP SMT, 0.1uF 0603 CER 16V 10% X7R | NIC COMPONENTS CORP | NMC0603X7R104K16TRPF |  | TRUE
1 | CAP0603 | C34 | 1uF | CAP SMT, 1.0uF 0603 CER 16V 10% X5R | PANASONIC | ECJ-1VB1C105K | PCC2224CT-ND | TRUE
4 | CAP0603 | C19, C25,C30,C35 | 27pF | CAP CER 27pF 50V C0G 5% 0603 | TDK Corporation | C1608C0G1H270J | 445-1274-2-ND | TRUE
2 | CAP0603 | C45, C46 | 22pF | CAP SMT, 22pF 0603 CER 50V 5% NP0 | PANASONIC | ECJ-1VC1H220J | PCC220ACVTR-ND | TRUE
2 | CAP0603 | C53, C54 | 56pF | CAP CER 56PF 50V 5% C0G 0603 | Murata | GRM1885C1H560JA01D | 490-1421-2-ND | TRUE
1 | CAP0805 | C27 | 10uF | CAP CER 10UF 6.3V Y5V 0805 | Murata | GRM21BF50J106ZE01L | 490-1746-1-ND | TRUE
2 | CAP_SMT_D | C48, C51 | 47uF | CAP 47UF 16V VS ELECT SMD | Panasonic - ECG | ECE-V1CA470SP | PCE3064CT-ND | TRUE
1 | CA-_SMT_F | C49 | 220uF | CAP ELECT 220UF 25V VS SMD | Panasonic - ECG | EEE-1EA221UP | PCE3902CT-ND | TRUE
0 | CONN_FPC_SD_54132 | J3 | No Load |  |  |  |  | N/A
1 | CRYSTAL_32KHZ | Y3 | 32KHz | CRYSTAL 32.768KHZ CYLINDER | ECS Inc. | ECS-3X8 | X801-ND | TRUE
2 | CRYSTAL_CS10 | Y1, Y2 | 25MHz | CRYSTAL 25.0000 MHZ 18PF SMD | CITIZEN | CS10-25.000MABJTR | 300-8105-1-ND | TRUE
1 | DE9S-FRS | P1 | RS-232 | CONN, D-SUB, 9P RECPT RT ANGLE W/ JACK SCREWS | TYCO | 7-747844-0 |  | TRUE
1 | DJ005B | J7 |  | CONN, JACK, 2.5mm DC PC MOUNT | KYCON | KLD-0202-B |  | TRUE
1 | RJ11_6PIN | J4 |  | CONN, MOD JACK 6-6 SIDE ENTRY LOW PROFILE | AMP/TYCO | 555165-1 | A9031-ND | TRUE
1 | HDR2X6 | J6 |  | 2x6 Header | 3M Electronic Solutions | 929852-01-06-10 | 517-852-01-06 Mouser | TRUE
1 | HDR2X14 | J5 |  | 2x14 Header | 3M Electronic Solutions | 929852-01-14-10 | 517-852-01-14 Mouser | TRUE
0 | ICE header | U1A | No Load | 25 pin male header | Samtec | MTMS-125-01-G-S-230 |  | TRUE
1 | JUMPER | JP9 |  | 1x2 Header |  |  |  | TRUE
0 | JUMPER | JP1, JP2, JP3, JP4, JP6, JP7, JP8, JP10, JP11, JP12, JP13, JP14, JP15, JP16, JP17, JP18, JP19, JP20, JP21, JP22, | No Load | 1x2 Header |  |  |  | TRUE
1 | SIP_3 | JP5 |  | 1x3 Header |  |  |  | TRUE
1 |  | LCD |  | LCD MODULE 16X2 CHARACTER | Lumex Opto | LCM-S01602DTR/M | 67-1781-ND | TRUE
9 | LED_LTL-PGK-TA | D1, D2, D3, D4, D5, D6, D7, D8, D9 |  | LED SMT, 2.7x3.5mm GREEN CLEAR PLCC-2 | FAIRCHILD SEMI | QTLP670NC-4 |  | TRUE
0 | CAP3528 | C6, C7, C8, C9, C14 | No Load |  |  |  |  | N/A
0 | CAP3528 | C2, C3, C4, C5 | No Load |  |  |  |  | N/A
1 | POT_MIN | R38 | 10K | POT 10K OHM THUMBWHEEL CERM ST | Bourns Inc. | 3352T-1-103LF | 3352T-103-ND | TRUE
2 | RES0603 | R30, R31 | 0 ohm | RES SMT, 0-OHM 0603 | PANASONIC | ERJ-3GSY0R00V | P0.0GTR-ND | TRUE
1 | RES0603 | R36 | 10 ohm | RES SMT, 10-OHM 1/10W 5% 0603 | PANASONIC | ERJ-3GEYJ100V | P10GTR-ND | TRUE
1 | RES0603 | R21 | 100 ohm | RES SMT, 100-OHM 1/10W 5% 0603 | PANASONIC | ERJ-3GEYJ101V | P100GTR-ND | TRUE
5 | RES0603 | R7, R8, R9, R14, R39 | 180 ohm | RES SMT, 180-OHM 1/10W 5% 0603 | Rohm | MCR03EZPJ181 | RHM180GCT-ND | TRUE
8 | RES0603 | R3, R4, R5, R6, R10, R11, R12, R13 | 49.9, 1% | RES 49.9 OHM 1/16W 1% 0603 SMD | Rohm | MCR03EZPFX49R9 | RHM49.9HCT-ND | TRUE
13 | RES0603 | R22, R23, R24, R25, R26, R27, R28, R29, R37, R40, R41, R42, R43 | 470 ohm | RES SMT, 470-OHM 1/10W 5% 0603 | PANASONIC | ERJ-3GEYJ471V | P470GTR-ND | TRUE
1 | RES0603 | R33 | 1K | RES SMT, 1.0K-OHM 1/10W 5% 0603 | PANASONIC | ERJ-3GEYJ102V | P1.0KGCT-ND | TRUE
1 | RES0603 | R17 | 1.3K | RES 1.3K OHM 1/10W 5% 0603 SMD | PANASONIC | ERJ-3GEYJ132V | P1.3KGTR-ND | TRUE
2 | RES0603 | R15, R20 | 2.32K 1% | RES 2.32K OHM 1/10W 1% 0603 SMD | PANASONIC | ERJ-3EKF2321V | P2.32KHTR-ND | TRUE
3 | RES0603 | R1, R2, R32 | 4.7K | RES SMT, 4.7K-OHM 1/10W 5% 0603 | PANASONIC | ERJ-3GEYJ472V | P4.7KGTR-ND | TRUE
7 | RES0603 | R16, R44, R45, R46, R47, R50, R51 | 10K | RES SMT, 10K-OHM 1/10W 5% 0603 | PANASONIC | ERJ-3GSYJ103V | P10KGTR-ND | TRUE
3 | RES0603 | R34, R53, R54 | 100K | RES SMT, 100K-OHM 1/10W 5% 0603 | PANASONIC | ERJ-3GSYJ104V | P100KGTR-ND | TRUE
1 | RES0603 | R35 | 1M | RES 1.0M OHM 1/10W 5% 0603 SMD | PANASONIC | ERJ-3GEYJ105V | P1.0MGCT-ND | TRUE
2 | RES1206 | R48, R49 | 2 ohm 1% | RES 2.00 OHM 1/4W 1% 1206 SMD | Rohm | MCR18EZHFL2R00 | RHM2.00FCT-ND | TRUE
0 | RES0603 | R18, R19 | No Load
1 | INDUCTOR-1210 | L2 | 60ohm | FERRITE 1.5A 60 OHM 1210 SMD | Steward | MI1210K600R-10 | 240-2416-1-ND | TRUE
2 | INDUCTOR-0603 | L1, L3 |  | FERRITE CHIP 120 OHM 25% 300mA 0603 | AEM | MCB0603G121PT-T | 637-MCB0603G121PT-T Mouser | TRUE
0 | RES0603 | R10 | No Load |  |  |  |  | N/A
5 | SW-PUSH_SMT | S1, S2, S3, S4, S5 |  | SWITCH TACT 6MM SMD MOM 230GF | Omron Electronics | B3S-1002 | SW416-ND | TRUE
2 |  | J1, J2 |  | Mag Jack | Bel Stewart | 08B0-1X1T-36-F |  | TRUE
0 | Alternate | J1, J2 |  | Pulse Jack | Pulse Engineering | JP011821UNL |  | TRUE
2 |  | TP3, TP5 |  | TEST POINT PC MULTI PURPOSE BLK | COMPONENTS CORP | TP-106-01-00 |  | TRUE
2 |  | TP2, TP4 |  | TEST POINT PC MULTI PURPOSE RED | COMPONENTS CORP | TP-106-01-02 |  | TRUE
1 |  | TP1 |  | TEST POINT PC MULTI PURPOSE WHT | Keystone Electronics | 5012 | 5012K-ND | TRUE
5 |  |  |  | BUMPON TALL TAPER SQ .50X.23 BK | 3M/ESM | SJ-5518 (BLACK) | SJ5518-0-ND | TRUE
1 |  |  |  | PCB |  | 05-60079_REV6 |  | TRUE
Changes from Rev 4 (original production version) to Rev 5
Delete | L1
Add | R52 | 0 ohm 0603
Add | L1, L3 | Ferrite bead 120 ohm 300mA 0603
Add | C53, C54 | 56pF 5% 0603
Changes from Rev 5 to Rev 6
Change | U3 to | PIC18F97J60-I/PT
Delete | R52 | 0 ohm 0603
Add | U6, U7 | NC7SB3157P6X
Add | R53, R54 | 100K 5% 0603
Change | C19,C25,C30,C35 to | 27pF 5% 0603

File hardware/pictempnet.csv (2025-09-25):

Id | Designator | Footprint | Quantity | Designation | Supplier and ref
1 | U5 | SOT-23 | 1 | TC1047xNB
2 | C6,C7,C32,C31,C26,C11,C2,C5,C20,C23,C13,C4,C24,C29,C3,C9,C25,C10,C28,C8,C27 | CP_EIA-1608-08_AVX-J_Pad1.25x1.05mm_HandSolder | 21 | 1 μF
3 | J3 | RJ12_Amphenol_54601-x06_Horizontal | 1 | RJ-12
4 | U3 | TO-263-3_TabPin2 | 1 | TC1262-3.3
5 | Y1,Y3 | Crystal_SMD_Qantek_QC5CB-2Pin_5x3.2mm | 2 | 25 MHz
6 | TP5,TP4,TP1,TP3,TP2 | TestPoint_Pad_1.5x1.5mm | 5 | TestPoint
7 | RV1 | Potentiometer_Bourns_3214W_Vertical | 1 | 10 kΩ
8 | R9,R11,R12,R10 | R_0603_1608Metric_Pad0.98x0.95mm_HandSolder | 4 | 49.9 Ω
9 | R13,R14,R4 | R_0603_1608Metric_Pad0.98x0.95mm_HandSolder | 3 | 180 Ω
10 | C12 | CP_EIA-1608-08_AVX-J_Pad1.25x1.05mm_HandSolder | 1 | 220 μF
11 | L1 | L_0603_1608Metric_Pad1.05x0.95mm_HandSolder | 1 | 100 mH
12 | J2 | BEL_08B0-1X1T-36-F | 1 | 08B0-1X1T-36-F
13 | D1 | D_DO-41_SOD81_P10.16mm_Horizontal | 1 | 1N4006
14 | R3,R2 | R_1206_3216Metric_Pad1.30x1.75mm_HandSolder | 2 | 2 Ω
15 | C19,C21,C15,C16,C22 | CP_EIA-1608-08_AVX-J_Pad1.25x1.05mm_HandSolder | 5 | 33 pF
16 | D2 | LED_0805_2012Metric_Pad1.15x1.40mm_HandSolder | 1 | PW LED
17 | C14 | CP_EIA-1608-08_AVX-J_Pad1.25x1.05mm_HandSolder | 1 | 47 μF
18 | U2 | LM2940S_5_NOPB_KTT3 | 1 | LM2940S-5.0/NOPB
19 | C17,C18 | CP_EIA-1608-08_AVX-J_Pad1.25x1.05mm_HandSolder | 2 | 22 pF
20 | R16,R17 | R_0603_1608Metric_Pad0.98x0.95mm_HandSolder | 2 | 10 kΩ
21 | C1 | CP_EIA-1608-08_AVX-J_Pad1.25x1.05mm_HandSolder | 1 | 10 μF
22 | U1 | TQFP-100_14x14mm_P0.5mm | 1 | PIC18F97J60-IPT
23 | R19,R18,R20 | R_0603_1608Metric_Pad0.98x0.95mm_HandSolder | 3 | 100 Ω
24 | C30 | CP_EIA-1608-08_AVX-J_Pad1.25x1.05mm_HandSolder | 1 | 1 nF
25 | U4 | QFN-28-1EP_6x6mm_P0.65mm_EP4.8x4.8mm | 1 | ENC28J60x-ML
26 | R5,R15 | R_0603_1608Metric_Pad0.98x0.95mm_HandSolder | 2 | 1 MΩ
27 | R1,R8 | R_0603_1608Metric_Pad0.98x0.95mm_HandSolder | 2 | 2.26 kΩ
28 | R7 | R_0603_1608Metric_Pad0.98x0.95mm_HandSolder | 1 | 1 kΩ
29 | J4 | LCD_LCM-S01602DTR_M | 1 | LCM-S01602DTR_M
30 | J1 | BarrelJack_CLIFF_FC681465S_SMT_Horizontal | 1 | Barrel Jack
31 | SW1 | SW_PUSH_6mm | 1 | SW_Push
32 | R6 | R_0603_1608Metric_Pad0.98x0.95mm_HandSolder | 1 | 4.7 kΩ
33 | Y2 | Crystal_SMD_TXC_9HT11-2Pin_2.0x1.2mm_HandSoldering | 1 | 32 kHz

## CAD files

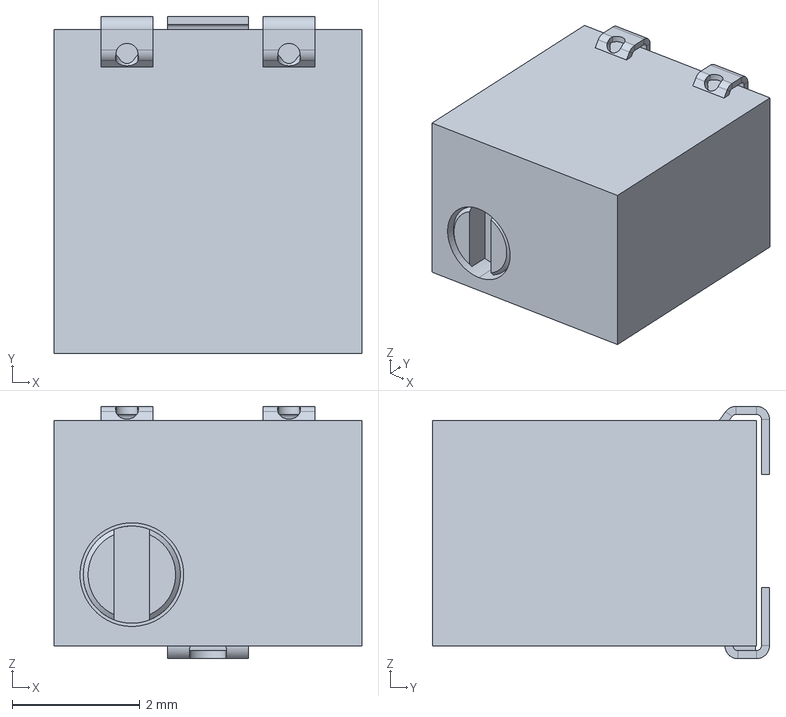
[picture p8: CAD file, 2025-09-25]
hardware/resources/step_models/3214W.stp
4.83 x 5.28 x 3.96 mm

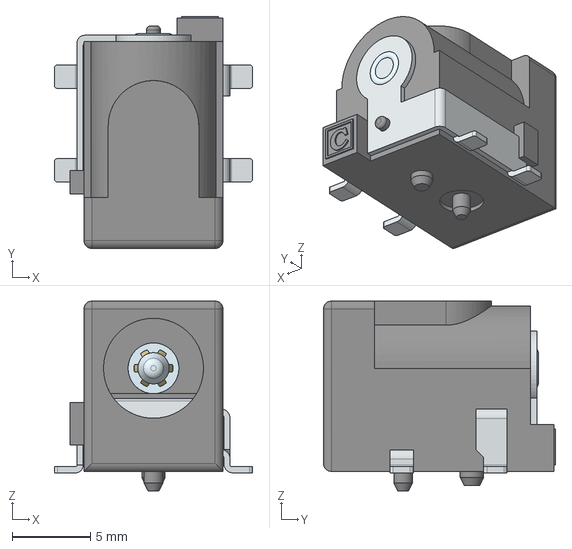
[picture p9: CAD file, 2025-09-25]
hardware/resources/step_models/DC_CON_FC681465S smd.stp
12.7 x 14.8 x 12.2 mm

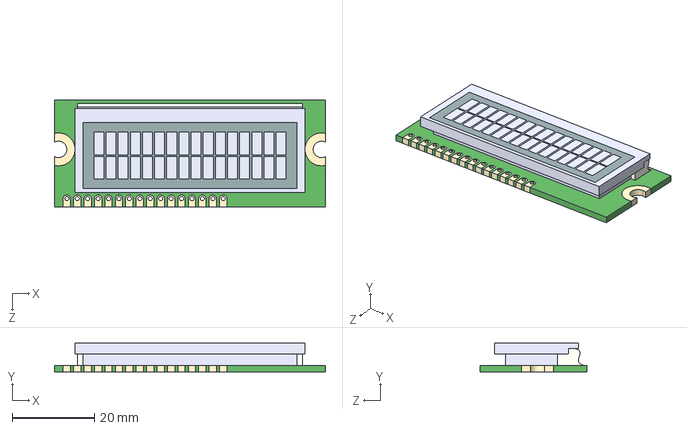
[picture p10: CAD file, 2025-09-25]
hardware/resources/step_models/LCM-S01602DTR_M.step
66.0 x 7.00 x 26.0 mm

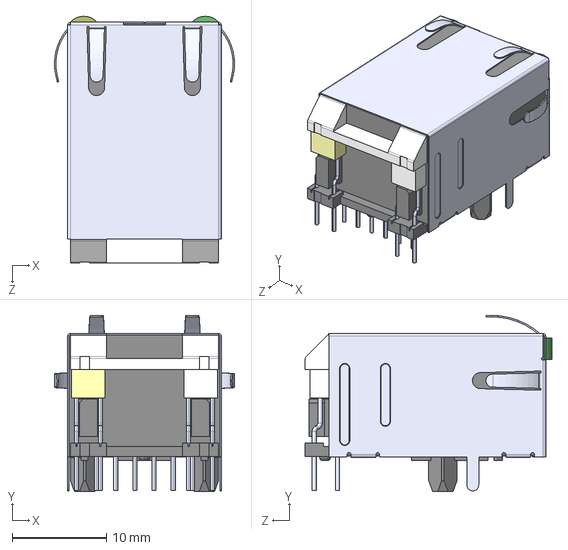
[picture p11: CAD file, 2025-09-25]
hardware/resources/step_models/08B0-1X1T-36-F.step
19.1 x 18.7 x 26.2 mm

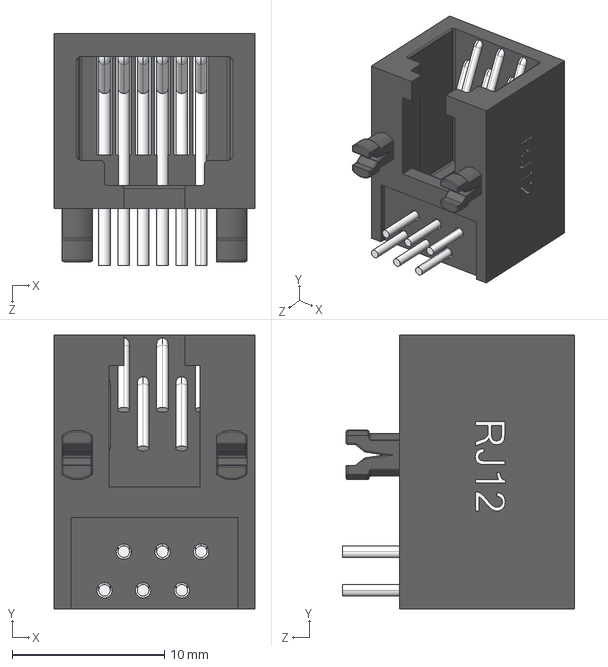
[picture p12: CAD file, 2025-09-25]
hardware/resources/step_models/-RJ12_54601-906WPLF.step
13.2 x 18.0 x 15.2 mm

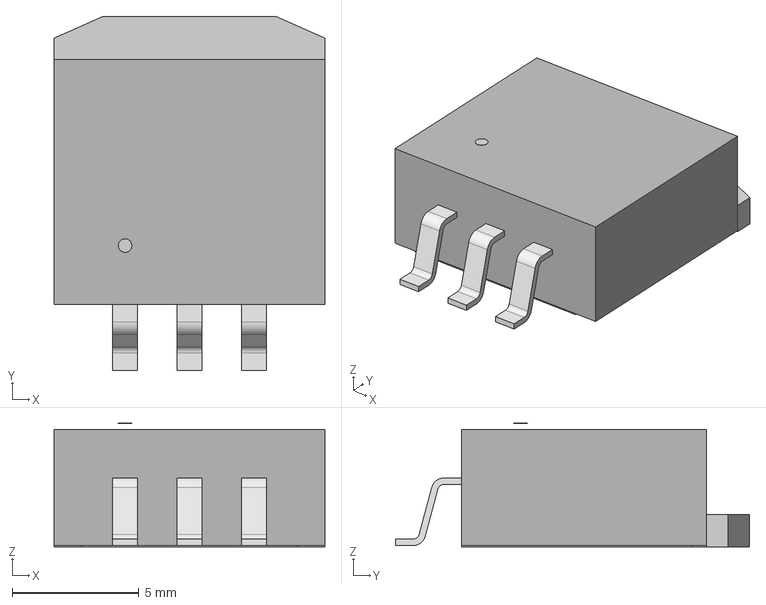
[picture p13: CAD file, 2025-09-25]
hardware/resources/step_models/LM2940S_5_NOPB.step
10.7 x 14.0 x 4.88 mm

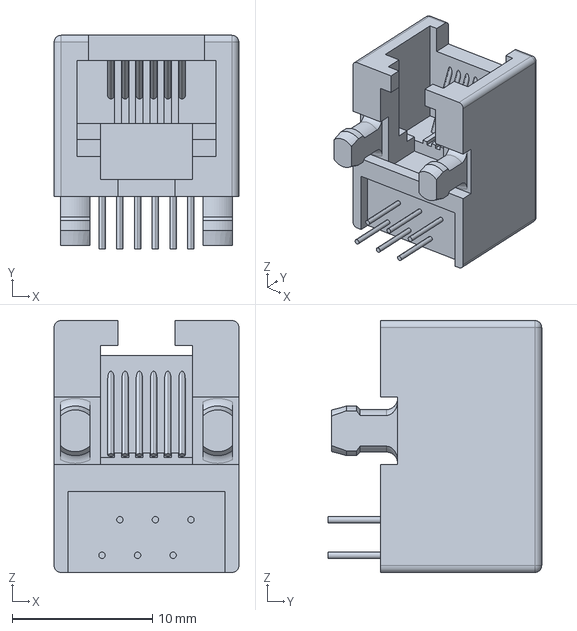
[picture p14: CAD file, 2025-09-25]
hardware/resources/step_models/54601-906WPLFc.stp
13.2 x 15.2 x 18.0 mm

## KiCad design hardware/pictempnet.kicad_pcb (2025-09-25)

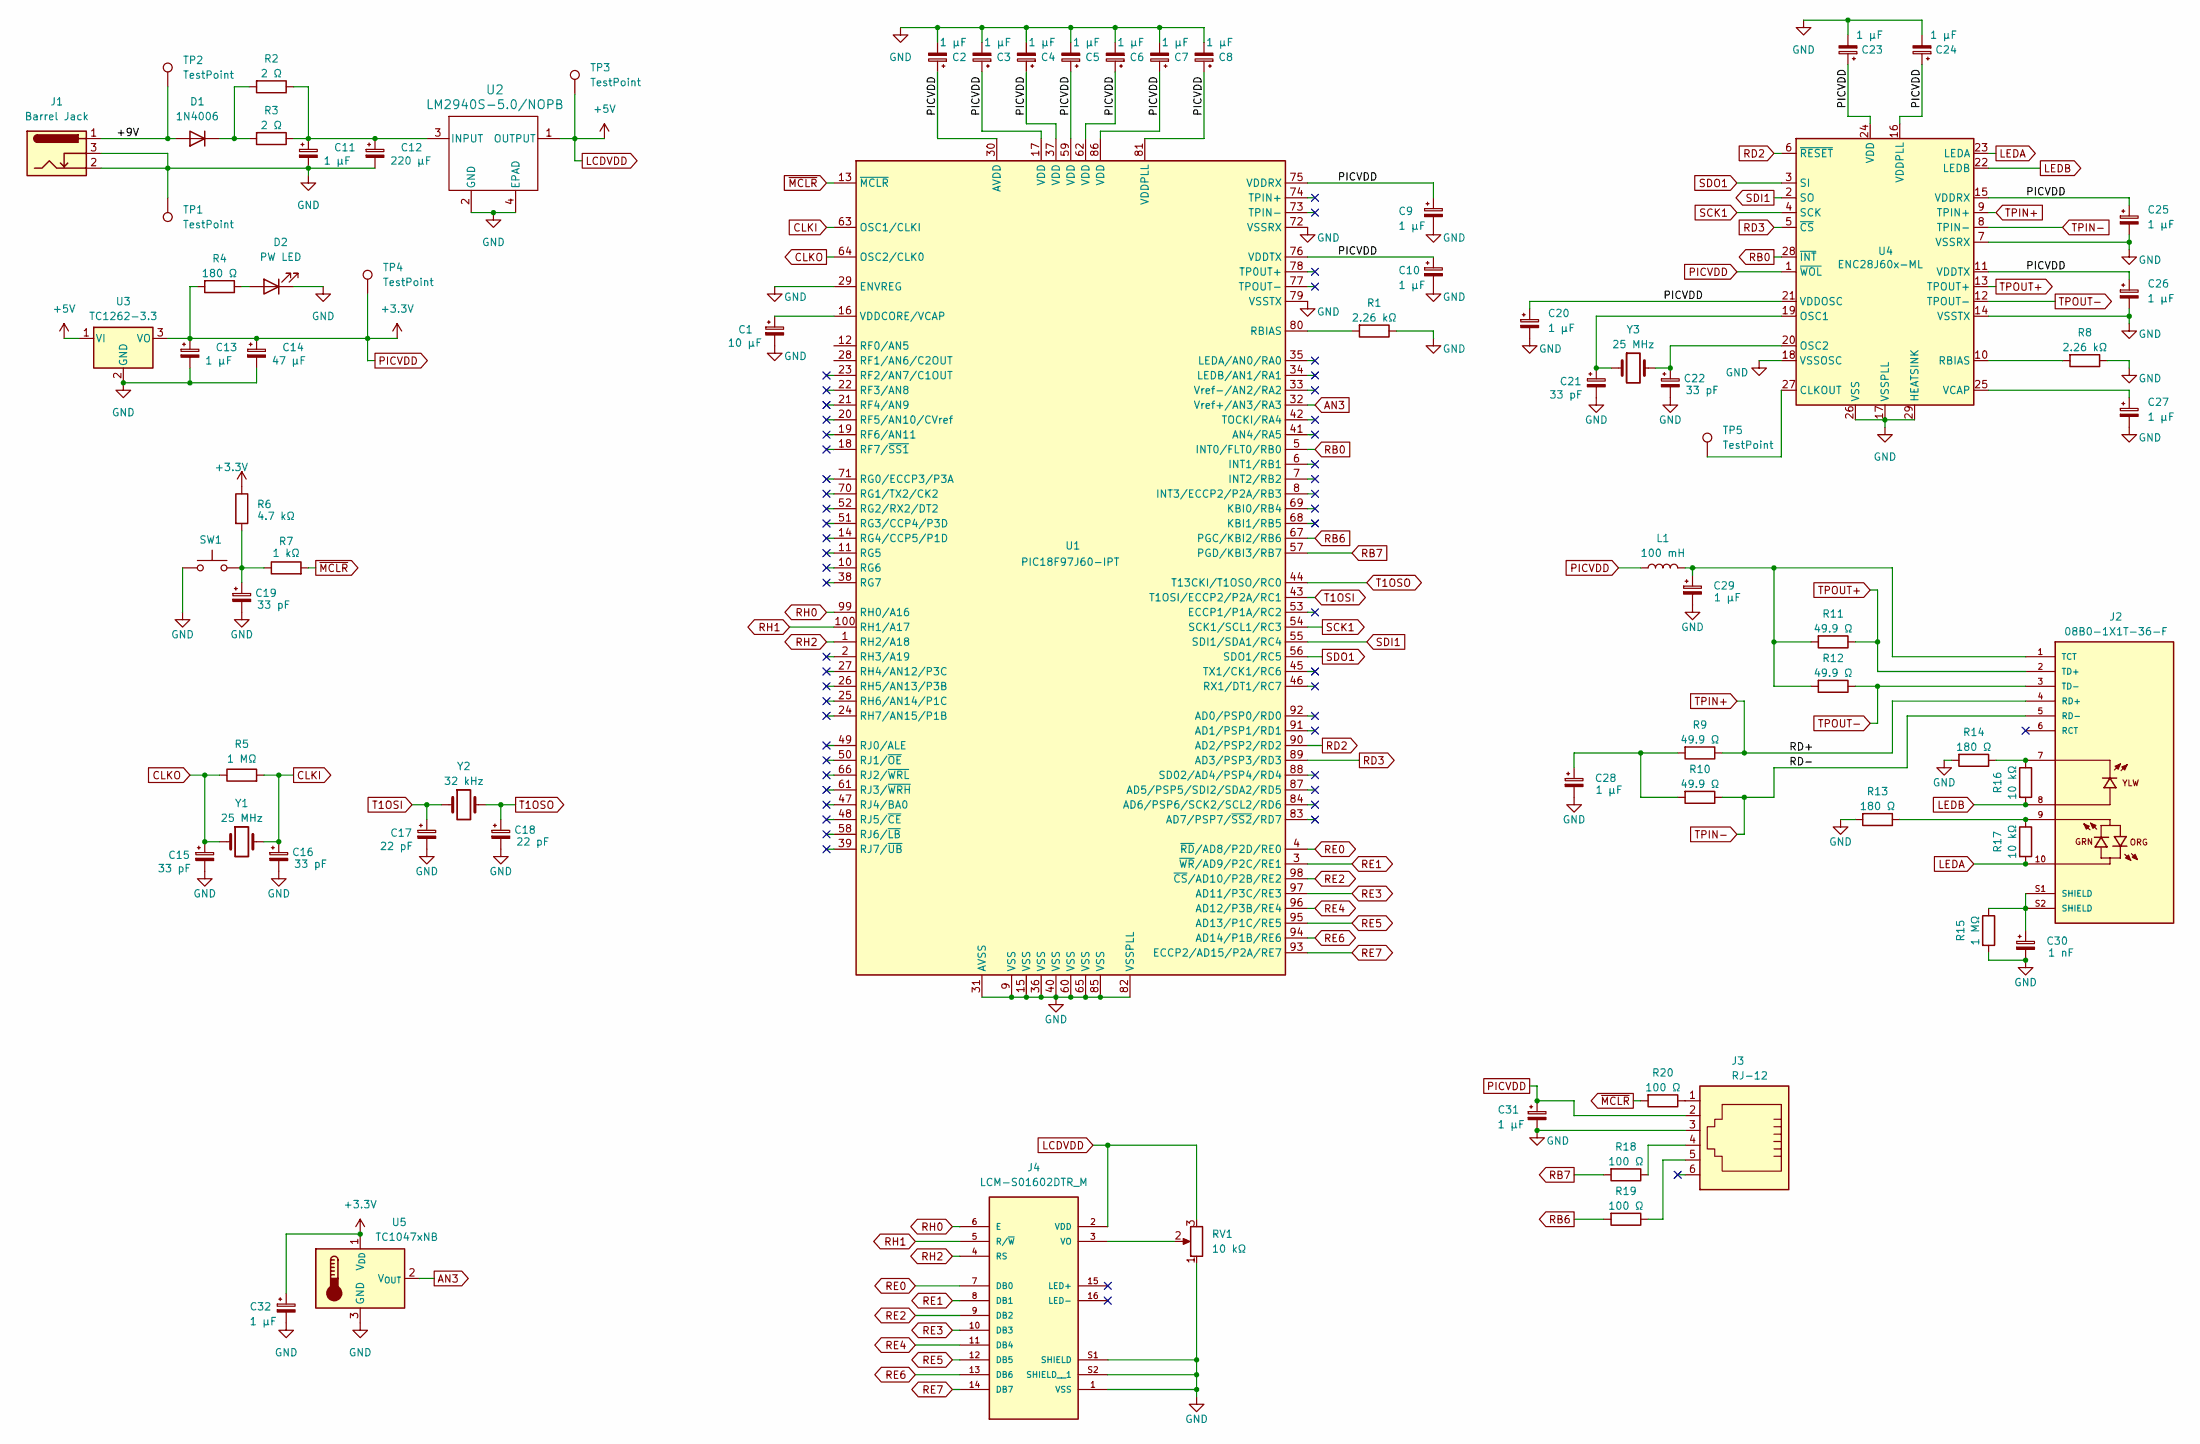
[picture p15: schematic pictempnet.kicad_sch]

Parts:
C1: 10 μF; CP_EIA-1608-08_AVX-J_Pad1.25x1.05mm_HandSolder
C2, C3, C4, C5, C6, C7, C8, C9, C10, C11, C13, C20, C23, C24, C25, C26, C27, C28, C29, C31, C32: 1 μF; CP_EIA-1608-08_AVX-J_Pad1.25x1.05mm_HandSolder
C12: 220 μF; CP_EIA-1608-08_AVX-J_Pad1.25x1.05mm_HandSolder
C14: 47 μF; CP_EIA-1608-08_AVX-J_Pad1.25x1.05mm_HandSolder
C15, C16, C19, C21, C22: 33 pF; CP_EIA-1608-08_AVX-J_Pad1.25x1.05mm_HandSolder
C17, C18: 22 pF; CP_EIA-1608-08_AVX-J_Pad1.25x1.05mm_HandSolder
C30: 1 nF; CP_EIA-1608-08_AVX-J_Pad1.25x1.05mm_HandSolder
D1: 1N4006; D_DO-41_SOD81_P10.16mm_Horizontal
D2: PW LED; LED_0805_2012Metric_Pad1.15x1.40mm_HandSolder
J1: Barrel Jack; BarrelJack_CLIFF_FC681465S_SMT_Horizontal
J2: 08B0-1X1T-36-F; BEL_08B0-1X1T-36-F; PARTREV D
J3: RJ-12; RJ12_Amphenol_54601-x06_Horizontal
J4: LCM-S01602DTR_M; LCD_LCM-S01602DTR_M; PARTREV 9/11/02
L1: 100 mH; L_0603_1608Metric_Pad1.05x0.95mm_HandSolder
R1, R8: 2.26 kΩ; R_0603_1608Metric_Pad0.98x0.95mm_HandSolder
R2, R3: 2 Ω; R_1206_3216Metric_Pad1.30x1.75mm_HandSolder
R4, R13, R14: 180 Ω; R_0603_1608Metric_Pad0.98x0.95mm_HandSolder
R5, R15: 1 MΩ; R_0603_1608Metric_Pad0.98x0.95mm_HandSolder
R6: 4.7 kΩ; R_0603_1608Metric_Pad0.98x0.95mm_HandSolder
R7: 1 kΩ; R_0603_1608Metric_Pad0.98x0.95mm_HandSolder
R9, R10, R11, R12: 49.9 Ω; R_0603_1608Metric_Pad0.98x0.95mm_HandSolder
R16, R17: 10 kΩ; R_0603_1608Metric_Pad0.98x0.95mm_HandSolder
R18, R19, R20: 100 Ω; R_0603_1608Metric_Pad0.98x0.95mm_HandSolder
RV1: 10 kΩ; Potentiometer_Bourns_3214W_Vertical
SW1: SW_Push; SW_PUSH_6mm
TP1, TP2, TP3, TP4, TP5: TestPoint; TestPoint_Pad_1.5x1.5mm
U1: PIC18F97J60-IPT; TQFP-100_14x14mm_P0.5mm
U2: LM2940S-5.0/NOPB; LM2940S_5_NOPB_KTT3
U3: TC1262-3.3; TO-263-3_TabPin2
U4: ENC28J60x-ML; QFN-28-1EP_6x6mm_P0.65mm_EP4.8x4.8mm
U5: TC1047xNB; SOT-23
Y1, Y3: 25 MHz; Crystal_SMD_Qantek_QC5CB-2Pin_5x3.2mm
Y2: 32 kHz; Crystal_SMD_TXC_9HT11-2Pin_2.0x1.2mm_HandSoldering

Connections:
/+9V: D1.2 (A), J1.1, TP2.1
AN3: U1.32 (Vref+/AN3/RA3), U5.2 (V_{OUT})
CLKI: C16.1, R5.2, U1.63 (OSC1/CLKI), Y1.2
CLKO: C15.1, R5.1, U1.64 (OSC2/CLK0), Y1.1
GND: C1.2, C2.2, C3.2, C4.2, C5.2, C6.2, C7.2, C8.2, C9.2, C10.2, C11.2, C12.2, C13.2, C14.2, C15.2, C16.2, C17.2, C18.2, C19.2, C20.2, C21.2, C22.2, C23.2, C24.2, C25.2, C26.2, C27.2, C28.2, C29.2, C30.2, C31.2, C32.2, D2.1 (K), J1.2, J1.3, J3.3, J4.1 (VSS), J4.S1 (SHIELD), J4.S2 (SHIELD__1), R1.1, R8.1, R13.2, R14.2, R15.2, RV1.1, SW1.1, TP1.1, U1.9 (VSS), U1.15 (VSS), U1.29 (ENVREG), U1.31 (AVSS), U1.36 (VSS), U1.40 (VSS), U1.60 (VSS), U1.65 (VSS), U1.72 (VSSRX), U1.79 (VSSTX), U1.82 (VSSPLL), U1.85 (VSS), U2.2 (GND), U2.4 (EPAD), U3.2 (GND), U4.7 (VSSRX), U4.14 (VSSTX), U4.17 (VSSPLL), U4.18 (VSSOSC), U4.26 (VSS), U4.29 (HEATSINK), U5.3 (GND)
LCDVDD: J4.2 (VDD), RV1.3, TP3.1, U2.1 (OUTPUT), U3.1 (VI)
LEDA: J2.10, R17.2, U4.23 (LEDA)
LEDB: J2.8, R16.2, U4.22 (LEDB)
unnamed: C19.1, R6.2, R7.1, SW1.2
unnamed: C28.1, R9.2, R10.2
unnamed: C30.1, J2.S1 (SHIELD), J2.S2 (SHIELD), R15.1
unnamed: D1.1 (K), R2.2, R3.2
unnamed: D2.2 (A), R4.1
unnamed: J2.7, R14.1, R16.1
unnamed: J2.9, R13.1, R17.1
unnamed: C29.1, J2.1 (TCT), L1.2, R11.2, R12.2
unnamed: J3.1, R20.1
unnamed: J3.4, R18.1
unnamed: J3.5, R19.1
unnamed: J4.3 (VO), RV1.2
unnamed: R1.2, U1.80 (RBIAS)
unnamed: C1.1, U1.16 (VDDCORE/VCAP)
unnamed: C11.1, C12.1, R2.1, R3.1, U2.3 (INPUT)
unnamed: TP5.1, U4.27 (CLKOUT)
unnamed: C21.1, U4.19 (OSC1), Y3.1
unnamed: C22.1, U4.20 (OSC2), Y3.2
unnamed: R8.2, U4.10 (RBIAS)
unnamed: C27.1, U4.25 (VCAP)
PICVDD: C2.1, C3.1, C4.1, C5.1, C6.1, C7.1, C8.1, C9.1, C10.1, C13.1, C14.1, C20.1, C23.1, C24.1, C25.1, C26.1, C31.1, C32.1, J3.2, L1.1, R4.2, R6.1, TP4.1, U1.17 (VDD), U1.30 (AVDD), U1.37 (VDD), U1.59 (VDD), U1.62 (VDD), U1.75 (VDDRX), U1.76 (VDDTX), U1.81 (VDDPLL), U1.86 (VDD), U3.3 (VO), U4.1 (~WOL), U4.11 (VDDTX), U4.15 (VDDRX), U4.16 (VDDPLL), U4.21 (VDDOSC), U4.24 (VDD), U5.1 (V_{DD})
RB0: U1.5 (INT0/FLT0/RB0), U4.28 (~INT)
RB6: R19.2, U1.67 (PGC/KBI2/RB6)
RB7: R18.2, U1.57 (PGD/KBI3/RB7)
RD2: U1.90 (AD2/PSP2/RD2), U4.6 (~RESET)
RD3: U1.89 (AD3/PSP3/RD3), U4.5 (~CS)
RE0: J4.7 (DB0), U1.4 (~RD/AD8/P2D/RE0)
RE1: J4.8 (DB1), U1.3 (~WR/AD9/P2C/RE1)
RE2: J4.9 (DB2), U1.98 (~CS/AD10/P2B/RE2)
RE3: J4.10 (DB3), U1.97 (AD11/P3C/RE3)
RE4: J4.11 (DB4), U1.96 (AD12/P3B/RE4)
RE5: J4.12 (DB5), U1.95 (AD13/P1C/RE5)
RE6: J4.13 (DB6), U1.94 (AD14/P1B/RE6)
RE7: J4.14 (DB7), U1.93 (ECCP2/AD15/P2A/RE7)
RH0: J4.6 (E), U1.99 (RH0/A16)
RH1: J4.5 (R/~W), U1.100 (RH1/A17)
RH2: J4.4 (RS), U1.1 (RH2/A18)
SCK1: U1.54 (SCK1/SCL1/RC3), U4.4 (SCK)
SDI1: U1.55 (SDI1/SDA1/RC4), U4.2 (SO)
SDO1: U1.56 (SDO1/RC5), U4.3 (SI)
T1OSI: C17.1, U1.43 (T1OSI/ECCP2/P2A/RC1), Y2.1
T1OSO: C18.1, U1.44 (T13CKI/T1OSO/RC0), Y2.2
TPIN+: J2.4 (RD+), R9.1, U4.9 (TPIN+)
TPIN-: J2.5 (RD-), R10.1, U4.8 (TPIN-)
TPOUT+: J2.2 (TD+), R11.1, U4.13 (TPOUT+)
TPOUT-: J2.3 (TD-), R12.1, U4.12 (TPOUT-)
~MCLR: R7.2, R20.2, U1.13 (~MCLR)

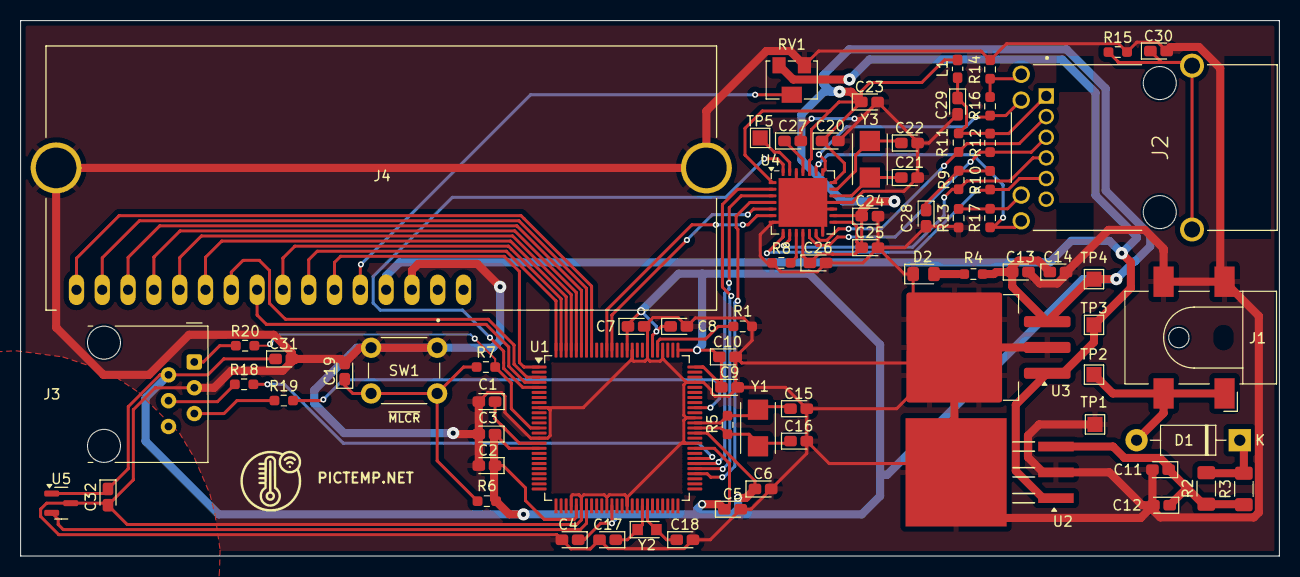
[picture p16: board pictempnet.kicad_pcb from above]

Board: 2 copper layers, 123.9 x 52.7 mm, 75 parts (0 on the bottom side), 55 nets.

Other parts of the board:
LOGO: LOGO; LOGO_BLACK

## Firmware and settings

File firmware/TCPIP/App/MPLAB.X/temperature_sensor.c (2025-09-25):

/* 
 * File:   Temp_sensor.c
 * Author: Greg
 *
 * Created on 13 November 2024, 14:41
 */

#include <p18f97j60.h>
#include "temperature_sensor.h"
#include <stdio.h>
#include <string.h>

void TMP_Init(void)
{
    TRISAbits.TRISA3 = 1;   // AN3 input
    ADCON0 = 0x0D;          // 0b 0000 1101     CH: AN3, ADON
    ADCON1 = 0x0B;          // 0b 0000 1011     AN0-AN3 analog input, else digital
    ADCON2 = 0xBE;          // 0b 1011 1110     Right justify, 20TAD ACQ time, Fosc/64 (~21.0kHz) - copied from the potentiometer demo program
    return;
}
unsigned int TMP_Read(void)
{
    ADCON0bits.GO = 1;                  // Start to sample and conversion
    while(!ADCON0bits.DONE) Nop();      // Waiting to finish
    return (ADRESH << 8) | ADRESL;      // Read the buffer
}
void ADC_to_TMP(unsigned char* buffer, unsigned int AD_value)
{
    float TMP = (((float)AD_value / 1023) * U_max_mV - 500) / TMP_Slope;    // convert 0-1023, (-40.00°C)-(125.00 °C)
    memset(buffer, 0, TMP_Buffer_Size);                                     // clear the buffer
    sprintf(buffer, "%.2f °C", TMP);                                        // load the value with .2 precision to the buffer
    return;
}

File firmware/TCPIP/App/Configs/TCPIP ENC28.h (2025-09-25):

/*********************************************************************
 *
 *	Microchip TCP/IP Stack Demo Application Configuration Header
 *
 *********************************************************************
 * FileName:        TCPIPConfig.h
 * Dependencies:    Microchip TCP/IP Stack
 * Processor:       PIC18, PIC24F, PIC24H, dsPIC30F, dsPIC33F, PIC32
 * Compiler:        Microchip C32 v1.10 or higher
 *					Microchip C30 v3.12 or higher
 *					Microchip C18 v3.34 or higher
 *					HI-TECH PICC-18 PRO 9.63PL2 or higher
 * Company:         Microchip Technology, Inc.
 *
 * Software License Agreement
 *
 * Copyright (C) 2002-2010 Microchip Technology Inc.  All rights
 * reserved.
 *
 * Microchip licenses to you the right to use, modify, copy, and
 * distribute:
 * (i)  the Software when embedded on a Microchip microcontroller or
 *      digital signal controller product ("Device") which is
 *      integrated into Licensee's product; or
 * (ii) ONLY the Software driver source files ENC28J60.c, ENC28J60.h,
 *		ENCX24J600.c and ENCX24J600.h ported to a non-Microchip device
 *		used in conjunction with a Microchip ethernet controller for
 *		the sole purpose of interfacing with the ethernet controller.
 *
 * You should refer to the license agreement accompanying this
 * Software for additional information regarding your rights and
 * obligations.
 *
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
 *
 * V5.36   ---- STACK_USE_MPFS support has been removed 
 ********************************************************************/
#ifndef __TCPIPCONFIG_H
#define __TCPIPCONFIG_H

#include "GenericTypeDefs.h"
#include "Compiler.h"
#define GENERATED_BY_TCPIPCONFIG "Version 1.0.4168.28618"

// =======================================================================
//   Application Options
// =======================================================================

/* Application Level Module Selection
 *   Uncomment or comment the following lines to enable or
 *   disabled the following high-level application modules.
 */
//#define STACK_USE_UART					// Application demo using UART for IP address display and stack configuration
//#define STACK_USE_UART2TCP_BRIDGE		// UART to TCP Bridge application example
//#define STACK_USE_IP_GLEANING
//#define STACK_USE_ICMP_SERVER			// Ping query and response capability
//#define STACK_USE_ICMP_CLIENT			// Ping transmission capability
//#define STACK_USE_HTTP2_SERVER			// New HTTP server with POST, Cookies, Authentication, etc.
//#define STACK_USE_SSL_SERVER			// SSL server socket support (Requires SW300052)
//#define STACK_USE_SSL_CLIENT			// SSL client socket support (Requires SW300052)
//#define STACK_USE_AUTO_IP               // Dynamic link-layer IP address automatic configuration protocol
#define STACK_USE_DHCP_CLIENT			// Dynamic Host Configuration Protocol client for obtaining IP address and other parameters
//#define STACK_USE_DHCP_SERVER			// Single host DHCP server
//#define STACK_USE_FTP_SERVER			// File Transfer Protocol (old)
//#define STACK_USE_SMTP_CLIENT			// Simple Mail Transfer Protocol for sending email
//#define STACK_USE_SNMP_SERVER			// Simple Network Management Protocol v2C Community Agent
//#define STACK_USE_SNMPV3_SERVER			// Simple Network Management Protocol v3 Agent
//#define STACK_USE_TFTP_CLIENT			// Trivial File Transfer Protocol client
//#define STACK_USE_GENERIC_TCP_CLIENT_EXAMPLE	// HTTP Client example in GenericTCPClient.c
#define STACK_USE_GENERIC_TCP_SERVER_EXAMPLE	// ToUpper server example in GenericTCPServer.c
//#define STACK_USE_TELNET_SERVER			// Telnet server
//#define STACK_USE_ANNOUNCE				// Microchip Embedded Ethernet Device Discoverer server/client
//#define STACK_USE_DNS					// Domain Name Service Client for resolving hostname strings to IP addresses
//#define STACK_USE_DNS_SERVER			// Domain Name Service Server for redirection to the local device
//#define STACK_USE_NBNS					// NetBIOS Name Service Server for repsonding to NBNS hostname broadcast queries
//#define STACK_USE_REBOOT_SERVER			// Module for resetting this PIC remotely.  Primarily useful for a Bootloader.
//#define STACK_USE_SNTP_CLIENT			// Simple Network Time Protocol for obtaining current date/time from Internet
//#define STACK_USE_UDP_PERFORMANCE_TEST	// Module for testing UDP TX performance characteristics.  NOTE: Enabling this will cause a huge amount of UDP broadcast packets to flood your network on the discard port.  Use care when enabling this on production networks, especially with VPNs (could tunnel broadcast traffic across a limited bandwidth connection).
//#define STACK_USE_TCP_PERFORMANCE_TEST	// Module for testing TCP TX performance characteristics
//#define STACK_USE_DYNAMICDNS_CLIENT		// Dynamic DNS client updater module
//#define STACK_USE_BERKELEY_API			// Berekely Sockets APIs are available
//#define STACK_USE_ZEROCONF_LINK_LOCAL	// Zeroconf IPv4 Link-Local Addressing
//#define STACK_USE_ZEROCONF_MDNS_SD		// Zeroconf mDNS and mDNS service discovery


// =======================================================================
//   Data Storage Options
// =======================================================================

/* MPFS Configuration
 *   MPFS is automatically included when required for other
 *   applications.  If your custom application requires it
 *   otherwise, uncomment the appropriate selection.
 */
//#define STACK_USE_MPFS2

/* MPFS Storage Location
 *   If html pages are stored in internal program memory,
 *   comment both MPFS_USE_EEPROM and MPFS_USE_SPI_FLASH, then
 *   include an MPFS image (.c or .s file) in the project.
 *   If html pages are stored in external memory, uncomment the
 *   appropriate definition.
 *
 *   Supported serial flash parts include the SST25VFxxxB series.
 */
#define MPFS_USE_EEPROM
//#define MPFS_USE_SPI_FLASH

/* EEPROM Addressing Selection
 *   If using the 1Mbit EEPROM, uncomment this line
 */
//#define USE_EEPROM_25LC1024

/* EEPROM Reserved Area
 *   Number of EEPROM bytes to be reserved before MPFS storage starts.
 *   These bytes host application configurations such as IP Address,
 *   MAC Address, and any other required variables.
 *
 *   For MPFS Classic, this setting must match the Reserved setting
 *	 on the Advanced Settings page of the MPFS2 Utility.
 */
#define MPFS_RESERVE_BLOCK				(137ul)

/* MPFS File Handles
 *   Maximum number of simultaneously open MPFS2 files.
 *   For MPFS Classic, this has no effect.
 */
#define MAX_MPFS_HANDLES				(7ul)


// =======================================================================
//   Network Addressing Options
// =======================================================================

/* Default Network Configuration
 *   These settings are only used if data is not found in EEPROM.
 *   To clear EEPROM, hold BUTTON0, reset the board, and continue
 *   holding until the LEDs flash.  Release, and reset again.
 */
#define MY_DEFAULT_HOST_NAME			"PICDEM"
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

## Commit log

2025-09-25 Add Micrichip library from Microchip Solutions v2011-06-02
    [Ethernet PICtail Plus Rev 5 BOM.xls, Ethernet PICtail Rev 5 BOM.xls, Fast 100Mbps Ethernet PICtail Plus Rev 1 BOM.xls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]
2025-09-25 Add temperature sensor module and update TCP/IP demo projects
    - Added temperature_sensor.c/h for temperature sensor support
    - Updated GenericTCPServer demo app for sensor integration
    - Modified project configuration to support new features
2025-09-25 Add KiCAD files
    [-RJ12_54601-906WPLF.step, 08B0-1X1T-36-F.step, 3214W.stp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]
2025-09-25 Move capacitor closer to IC for better decoupling; reorganize project folders (symbols, footprints, 3D models)
    [-RJ12_54601-906WPLF.step, 08B0-1X1T-36-F.step, 3214W.stp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]
2025-09-25 Add BOM file: pictempnet.csv
    [pictempnet.csv]
